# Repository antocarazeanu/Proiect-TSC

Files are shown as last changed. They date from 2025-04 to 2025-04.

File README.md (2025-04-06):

## README - Proiect TSC 2025
## Titlu Proiect: Ebook Reader
## Nume: Carazeanu Antonio-Christian
## Grupa: 332CC

Cuprins:

0. Descrierea generala
1. Diagrama bloc
2. BOM - Bill of Materials
3. Arhitectura hardware
4. Pini utilizați pe ESP32-C6 și justificare
5. Probleme intampinate
6. Observatii

## 0. Descriere Generală:
Proiectul a avut ca scop realizarea unui Ebook Reader ieftin si OpenSource din
perspectiva unui Arhitect de Sistem. Acest dispozitiv poate fi scos pentru a fi
produs in masa.

Am urmat toți pașii standard de proiectare, începând de la schematic, continuând
cu layout-ul PCB, modelare 3D și integrarea finală într-o carcasă.

## 1. Diagrama bloc
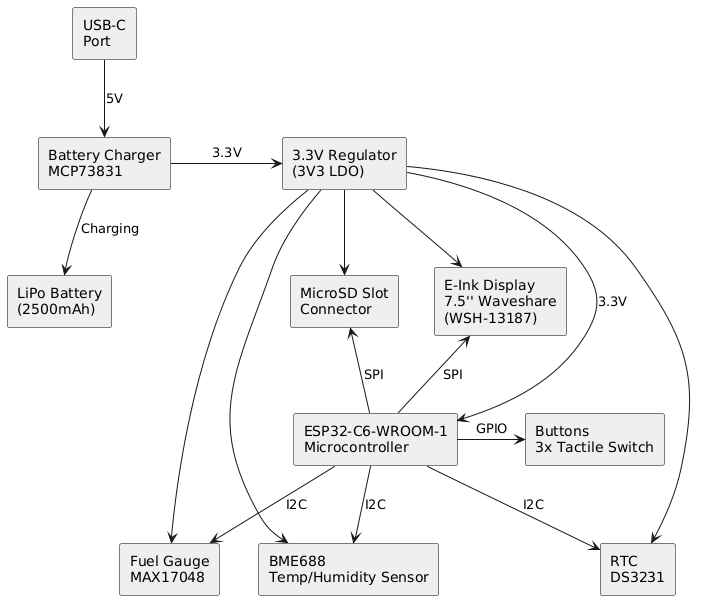
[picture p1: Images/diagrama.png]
Diagrama


## 2. BOM - Bill of Materials
| Device | Value | Check_Price | Datasheet |
|---|---|---|---|
| ADAFRUIT_LEDCHIP-LED0603 | - | [Link](https://www.snapeda.com/parts/KP-1608SURCK/Kingbright/view-part/?ref=search&t=LED%200603) | [Link](https://www.snapeda.com/parts/KP-1608SURCK/Kingbright/datasheet/) |
| SJ | - | [Link](https://grabcad.com/library/solder-jumpers-1) | - |
| EAGLE-LTSPICE_C | 0.1uF/50V | [Link](https://componentsearchengine.com/part-view/CC0402MRX5R5BB106/YAGEO) | [Link](https://componentsearchengine.com/Datasheets/2/CC0402MRX5R5BB106.pdf) |
| ESP32_WROVER_EAGLE-LTSPICE_R | 0.47 | [Link](https://componentsearchengine.com/part-view/R0402%201%25%20100%20K%20(RC0402FR-07100KL)/YAGEO) | [Link](https://www.yageo.com/upload/media/product/products/datasheet/rchip/PYu-RC_Group_51_RoHS_L_12.pdf) |
| ESP32_WROVER_EAGLE-LTSPICE_R | 100K | [Link](https://componentsearchengine.com/part-view/R0402%201%25%20100%20K%20(RC0402FR-07100KL)/YAGEO) | [Link](https://www.yageo.com/upload/media/product/products/datasheet/rchip/PYu-RC_Group_51_RoHS_L_12.pdf) |
| EAGLE-LTSPICE_C | 100nF | [Link](https://componentsearchengine.com/part-view/CC0402MRX5R5BB106/YAGEO) | [Link](https://componentsearchengine.com/Datasheets/2/CC0402MRX5R5BB106.pdf) |
| RCL_CPOL-EUCT3528 | 100uF TANT | [Link](https://www.snapeda.com/parts/TAJB475K025RNJ/AVX/view-part/?ref=dk&t=capacitor%203528&con_ref=None) | [Link](https://s3.amazonaws.com/snapeda/datasheet/TAJB475K025RNJ_AVX.pdf) |
| ESP32_WROVER_EAGLE-LTSPICE_R | 10K | [Link](https://componentsearchengine.com/part-view/R0402%201%25%20100%20K%20(RC0402FR-07100KL)/YAGEO) | [Link](https://www.yageo.com/upload/media/product/products/datasheet/rchip/PYu-RC_Group_51_RoHS_L_12.pdf) |
| EAGLE-LTSPICE_C | 10uF | [Link](https://componentsearchengine.com/part-view/CC0402MRX5R5BB106/YAGEO) | [Link](https://componentsearchengine.com/Datasheets/2/CC0402MRX5R5BB106.pdf) |
| 112A-TAAR-R03_ATTEND | 112A-TAAR-R03_ATTEND | [Link](https://store.comet.srl.ro/Catalogue/Product/43497/) | [Link](https://store.comet.bg/download-file.php?id=8824) |
| ESP32_WROVER_EAGLE-LTSPICE_R | 15 | [Link](https://componentsearchengine.com/part-view/R0402%201%25%20100%20K%20(RC0402FR-07100KL)/YAGEO) | [Link](https://www.yageo.com/upload/media/product/products/datasheet/rchip/PYu-RC_Group_51_RoHS_L_12.pdf) |
| EAGLE-LTSPICE_C | 1uF | [Link](https://componentsearchengine.com/part-view/CC0402MRX5R5BB106/YAGEO) | [Link](https://componentsearchengine.com/Datasheets/2/CC0402MRX5R5BB106.pdf) |
| EAGLE-LTSPICE_C | 1uF/50V | [Link](https://componentsearchengine.com/part-view/CC0402MRX5R5BB106/YAGEO) | [Link](https://componentsearchengine.com/Datasheets/2/CC0402MRX5R5BB106.pdf) |
| ESP32_WROVER_EAGLE-LTSPICE_R | 2.2 | [Link](https://componentsearchengine.com/part-view/R0402%201%25%20100%20K%20(RC0402FR-07100KL)/YAGEO) | [Link](https://www.yageo.com/upload/media/product/products/datasheet/rchip/PYu-RC_Group_51_RoHS_L_12.pdf) |
| ESP32_WROVER_EAGLE-LTSPICE_R | 200 | [Link](https://componentsearchengine.com/part-view/R0402%201%25%20100%20K%20(RC0402FR-07100KL)/YAGEO) | [Link](https://www.yageo.com/upload/media/product/products/datasheet/rchip/PYu-RC_Group_51_RoHS_L_12.pdf) |
| ESP32_WROVER_SPARKFUN-DISCRETESEMI_MOSFET_PCH-DMG2305UX-7 | 20V/4.2A/52m?/1.4W | [Link](https://componentsearchengine.com/part-view/DMG2305UX-7/Diodes%20Incorporated) | [Link](https://www.diodes.com//assets/Datasheets/DMG2305UX.pdf) |
| ESP32_WROVER_EAGLE-LTSPICE_R | 2K | [Link](https://componentsearchengine.com/part-view/R0402%201%25%20100%20K%20(RC0402FR-07100KL)/YAGEO) | [Link](https://www.yageo.com/upload/media/product/products/datasheet/rchip/PYu-RC_Group_51_RoHS_L_12.pdf) |
| EAGLE-LTSPICE_C | 4.7uF | [Link](https://componentsearchengine.com/part-view/CC0402MRX5R5BB106/YAGEO) | [Link](https://componentsearchengine.com/Datasheets/2/CC0402MRX5R5BB106.pdf) |
| EAGLE-LTSPICE_C | 4.7uF/25V | [Link](https://componentsearchengine.com/part-view/CC0402MRX5R5BB106/YAGEO) | [Link](https://componentsearchengine.com/Datasheets/2/CC0402MRX5R5BB106.pdf) |
| ESP32_WROVER_EAGLE-LTSPICE_R | 5k1 | [Link](https://componentsearchengine.com/part-view/R0402%201%25%20100%20K%20(RC0402FR-07100KL)/YAGEO) | [Link](https://www.yageo.com/upload/media/product/products/datasheet/rchip/PYu-RC_Group_51_RoHS_L_12.pdf) |
| 744043680IND_4828-WE-TPC_WRE | 68uH | [Link](https://ro.mouser.com/ProductDetail/Wurth-Elektronik/744043680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.) | [Link](https://www.we-online.com/components/products/datasheet/744043680.pdf) |
| BD5229G-TR | BD5229G-TR | [Link](https://componentsearchengine.com/part-view/BD5229G-TR/ROHM%20Semiconductor) | [Link](https://datasheet.datasheetarchive.com/originals/distributors/Datasheets_SAMA/f2b9741ef86007909f138d561a359946.pdf) |
| ESP32_WROVER_BME680_BME680 | BME688 | [Link](https://www.snapeda.com/parts/BME680/Bosch/view-part/?welcome=home) | [Link](https://www.snapeda.com/parts/BME680/Bosch%20Sensortec/datasheet/) |
| BUTTON_CUSYOMV1V2 | BUTTON_CUSYOMV1V2 | [Link](https://industry.panasonic.com/global/en/products/control/switch/light-touch/number/evqpuj02k) | [Link](https://industry.panasonic.com/global/en/downloads?tab=catalog&small_g_cd=203&part_no=EVQPUJ02K) |
| CPH3225A | CPH3225A | [Link](https://www.snapeda.com/parts/CPH3225A/Seiko+Instruments/view-part/?ref=eda) | [Link](https://www.snapeda.com/parts/CPH3225A/Seiko+Instruments/view-part/?ref=eda ) |
| DS3231SN# | DS3231SN# | [Link](https://www.snapeda.com/parts/DS3231SN%23/Analog+Devices/view-part/?ref=eda) | [Link](https://www.snapeda.com/parts/DS3231SN%23/Analog+Devices/view-part/?ref=eda) |
| ESP32-C6-WROOM-1-N8 | ESP32-C6-WROOM-1-N8 | [Link](https://www.snapeda.com/parts/ESP32-C6-WROOM-1-N8/Espressif+Systems/view-part/?ref=eda) | [Link](https://www.snapeda.com/parts/ESP32-C6-WROOM-1-N8/Espressif+Systems/view-part/?ref=eda) |
| ESP32C6_VARISTORCN1812 | ESP32C6_VARISTORCN1812 | [Link](https://www.mouser.co.uk/ProductDetail/EPCOS-TDK/B72520T0350K062?qs=dEfas%2FXlABIszF52uu7vrg%3D%3D) | [Link](https://www.tdk-electronics.tdk.com/inf/75/db/CTVS_14/Surge_protection_series.pdf) |
| ESP32_WROVER_SPARKFUN-IC-POWER_MCP73831 | ESP32_WROVER_SPARKFUN-IC-POWER_MCP73831 | [Link](https://ro.mouser.com/ProductDetail/Microchip-Technology/MCP73831T-2ACI-OT?qs=yUQqVecv4qvbBQBGbHx0Mw%3D%3D) | [Link](https://ro.mouser.com/datasheet/2/268/MCP73831_Family_Data_Sheet_DS20001984H-3441711.pdf) |
| FH34SRJ-24S-0.5SH_99_ | FH34SRJ-24S-0.5SH_99_ | [Link](https://componentsearchengine.com/part-view/FH34SRJ-24S-0.5SH(99)/Hirose) | [Link](https://www.hirose.com/en/product/document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) |
| MAX17048G+T10 | MAX17048G+T10 | [Link](https://www.snapeda.com/parts/MAX17048G+T10/Analog+Devices/view-part/?ref=eda) | [Link](https://www.snapeda.com/parts/MAX17048G+T10/Analog+Devices/view-part/?ref=eda) |
| MBR0530. | MBR0530. | [Link](https://www.snapeda.com/parts/MBR0530/Onsemi/view-part/?ref=eda) | [Link](https://www.snapeda.com/parts/MBR0530/ON%20Semiconductor/datasheet/) |
| PGB1010603MR. | PGB1010603MR. | [Link](https://www.snapeda.com/parts/PGB1010603MR/Littelfuse/view-part/?ref=eda) | [Link](https://www.snapeda.com/parts/PGB1010603MR/Littelfuse%20Inc./datasheet/) |
| QWIIC_CONNECTORJS-1MM | QWIIC_RIGHT_ANGLE | [Link](https://www.digikey.lt/en/models/926710 ) | [Link](https://www.digikey.lt/en/models/926710) |
| SAMACSYS_PARTS_USB4110-GF-A | SAMACSYS_PARTS_USB4110-GF-A | [Link](https://componentsearchengine.com/part-view/USB4110-GF-A/GCT%20(GLOBAL%20CONNECTOR%20TECHNOLOGY)) | [Link](https://gct.co/files/drawings/usb4110.pdf) |
| ESP32_WROVER_AVX---SD0805S020S1R0_AVX_SD0805S020S1R0_0_0AVX_SD0805S020S1R0_0_0 | SD0805S020S1R0 | [Link](https://ro.mouser.com/ProductDetail/KYOCERA-AVX/SD0805S020S1R0?qs=jCA%252BPfw4LHbpkAoSnwrdjw%3D%3D) | [Link](http://datasheets.avx.com/schottky.pdf) |
| SI1308EDL-T1-GE3 | SI1308EDL-T1-GE3 | [Link](https://www.snapeda.com/parts/SI1308EDL-T1-GE3/Vishay+Siliconix/view-part/?ref=eda) | [Link](https://www.snapeda.com/parts/SI1308EDL-T1-GE3/Vishay+Siliconix/view-part/?ref=eda) |
| TPV1 | TPV1 | Custom made | - |
| USBLC6-2SC6Y | USBLC6-2SC6Y | [Link](https://www.snapeda.com/parts/USBLC6-2SC6Y/STMicroelectronics/view-part/?ref=eda) | [Link](https://www.snapeda.com/parts/USBLC6-2SC6Y/STMicroelectronics/view-part/?ref=eda) |
| W25Q512JVEIQ | W25Q512JVEIQ | [Link](https://www.snapeda.com/parts/W25Q512JVEIQ/Winbond+Electronics/view-part/?ref=eda) | [Link](https://www.snapeda.com/parts/W25Q512JVEIQ/Winbond+Electronics/view-part/?ref=eda) |
| XC6220A331MR-G | XC6220A331MR-G | [Link](https://componentsearchengine.com/part-view/XC6220A331MR-G/Torex) | [Link](https://product.torexsemi.com/system/files/series/xc6220.pdf) |

## 3. Arhitectura Hardware

Descriem în continuare componentele hardware cheie și funcționalitatea acestora în cadrul dispozitivului:

| Nr. | Componentă Principală |
|-----|---|
| 1 | Microcontroller – ESP32-C6-WROOM-1 |
| 2 | Ecran E-Ink – Waveshare WSH-13187, 7.5”  |
| 3 | Senzor Ambiental – Bosch BME688 |
| 4 | Sistem de Alimentare și Baterie |
| 5 | Butoane de Control – 3x Tactile Switch |
| 6 | Conector USB-C |
| 7 | Port Extensie Qwiic / STEMMA QT (I²C) |
| 8 | Soclu MicroSD – Attend 112A-TAAR-R03 |
| 9 | Ceas Timp Real (RTC) – DS3231 |

### 3.1. Unitatea Centrală – Microcontroller ESP32-C6-WROOM-1

-   **Unitate de Procesare:** RISC-V pe 32 de biți, tactat la 160MHz
-   **Memorie:** 512KB SRAM integrat + 8MB memorie flash externă (model W25Q512JVEIQ)
-   **Opțiuni de Comunicare:** Wi-Fi 6 (standard 802.11ax), Bluetooth 5 LE, interfață USB 2.0 Full-Speed
-   **Interfețe Disponibile:** SPI, I²C, UART, multiple porturi GPIO
-   **Consum Energetic:** Sub 50µA în modul deep sleep; diverse moduri de consum redus sunt implementate
-   **Funcții de Securitate:** Include secure boot, criptare pentru memoria flash și accelerare hardware pentru criptografie

### 3.2. Afișajul Electronic – Ecran E-Ink Waveshare WSH-13187, 7.5”

-   **Rezoluție:** 800x480 pixeli, imagine monocromă
-   **Modalitate de Conectare:** Interfață SPI (4 fire) plus linii de control CS, DC, RST, BUSY
-   **Consum Energetic:** Aproximativ 15–25mA în timpul actualizării imaginii; consum neglijabil în stare statică
-   **Rațiunea Alegerii:** Consumul energetic aproape nul când imaginea nu se schimbă, optim pentru aplicații tip e-reader

### 3.3. Senzorul Ambiental Integrat – Bosch BME688

-   **Parametri Măsurați:** Temperatură, Umiditate relativă, Presiune atmosferică, Indice al Calității Aerului (estimare eCO2, TVOC)
-   **Acuratețe:** ±1°C pentru temperatură, ±3% pentru umiditate, ±1 hPa pentru presiune
-   **Modalitate de Conectare:** Interfață I²C (operând la 400kHz)
-   **Consum Energetic:** 2.1µA în standby, maxim 3.6mA în timpul măsurătorilor active
-   **Rațiunea Alegerii:** Soluție compactă multi-senzor, potrivită pentru monitorizarea condițiilor ambientale

### 3.4. Sistemul de Alimentare și Gestionarea Energiei

-   **Sursa de Energie:** Acumulator Li-Po de 3.7V cu o capacitate de 2500mAh
-   **Monitorizare Baterie:** Circuit integrat MAX17048 (comunică prin I²C)
-   **Circuit de Încărcare:** MCP73831 – permite încărcarea cu 5V/1A via portul USB-C
-   **Regulator de Tensiune:** LDO ce furnizează o tensiune stabilă de 3.3V pentru întregul circuit
-   **Consum Total Estimativ:**
    -   În mod activ: între 100 și 150mA
    -   În mod deep sleep: sub 50µA

### 3.5. Interfața cu Utilizatorul – 3x Butoane Tactile

-   **Model Buton:** Panasonic EVQ-Q2A03W
-   **Conectare Electrică:** Legate la pini GPIO, cu circuit de debounce hardware (filtru RC)
-   **Funcționalități Asignate:** Navigare prin meniuri, avansare/revenire pagină, confirmare acțiuni

### 3.6. Conectorul USB-C

-   **Funcționalități Principale:** Încărcarea bateriei și transferul de date (conform standardului USB 2.0)
-   **Măsuri de Protecție:** Protecție ESD integrată și terminații conforme standardului
-   **Posibilități Suplimentare:** Actualizări software OTA (Over-The-Air) via Wi-Fi sau actualizare firmware prin conexiune USB

### 3.7. Portul de Extensie Qwiic / STEMMA QT (I²C)

-   **Configurație Pini:** VCC (Alimentare), GND (Masă), SDA (Date I²C), SCL (Ceas I²C)
-   **Scop/Beneficii:** Permite conectarea rapidă a modulelor și senzorilor externi compatibili I²C

### 3.8. Soclul pentru Card MicroSD – Attend 112A-TAAR-R03

-   **Rol Principal:** Oferă spațiu de stocare extern (pentru cărți electronice, fișiere jurnal, firmware etc.)
-   **Modalitate de Conectare:** Interfață SPI

### 3.9. Ceasul Timp Real (RTC) – DS3231

-   **Acuratețe:** Deviație maximă de ±2 părți per milion (ppm)
-   **Modalitate de Conectare:** Interfață I²C
-   **Alimentare de Backup:** Asigurată de un supercapacitor

---

### Protocoale de Comunicare și Interfețe Utilizate

| Protocol/Interfață | Componente Conectate |
|---|---|
| **SPI** | Ecran E-Paper, Memorie Flash externă, Card SD (SPI) |
| **I²C** | Senzor BME688, Fuel Gauge MAX17048, RTC DS3231, Port Qwiic/Stemma |
| **USB** | Încărcare și comunicație de date via USB-C |
| **GPIO** | Butoane, Linii control afișaj, Activare încărcare |

---

### Profil de Consum Energetic (Estimări)

| Stare/Componentă | Consum Estimativ |
|---|---|
| ESP32-C6 (mod activ) | 80–100mA |
| Actualizare E-Paper | 15–25mA |
| Senzor BME688 (activ)  | 3.6mA |
| Fuel Gauge MAX17048 | ~50µA |
| RTC DS3231 | 3.5mA / 1µA backup |
| Deep Sleep (Total) | <50–100µA |

---

### Specificații Fizice și Constructive

-   **Mărimi Fizice:** 175 x 114 x 10 mm
-   **Masa Dispozitivului:** Aproximativ 250g
-   **Material Carcasă:** ABS sau policarbonat, cu design ergonomic
-   **Montare Afișaj:** Integrat într-un decupaj specific al carcasei
-   **Detalii de Fabricație:** PCB cu 2 straturi, finisaj ENIG, carcasă obținută prin injecție de plastic

## 4. Pini utilizați pe ESP32-C6 și justificare

| Pin ESP32-C6 | Componentă / Semnal | De ce? |
|---|---|---|
| GPIO1 | I²C SDA (BME688, MAX17048, DS3231, Qwiic) | Linie partajată I²C – economisește pini și permite extinderea facilă |
| GPIO2 | I²C SCL (BME688, MAX17048, DS3231, Qwiic) | Clock I²C pentru toți senzorii și extensii Qwiic |
| GPIO5 | SPI MISO (E-Paper, Flash extern) | Linie comună de intrare date în SPI |
| GPIO6 | SPI MOSI (E-Paper, Flash extern) | Linie de ieșire date către e-paper și flash |
| GPIO7 | SPI CLK | Semnal de clock pentru magistrala SPI |
| GPIO8 | E-Paper CS | Selectează afișajul pe magistrala SPI |
| GPIO9 | E-Paper DC (Data/Command) | Comută între comandă și date către e-paper |
| GPIO10 | E-Paper RST | Reset hardware e-paper |
| GPIO11 | E-Paper BUSY | Pin de stare (ocupat/liber) de la display |
| GPIO12 | Button #1 | Intrare digitală pentru navigare pagină înainte |
| GPIO13 | Button #2 | Intrare digitală pentru navigare pagină înapoi |
| GPIO14 | Button #3 | Intrare digitală pentru selectare/opțiune |
| GPIO15 | MAX17048 ALERT (opțional) | Pin de alertă nivel scăzut baterie |
| GPIO16 | USB D+ (intern la USB PHY) | Linie USB 2.0 (fixă pe ESP32-C6) |
| GPIO17 | USB D- (intern la USB PHY) | Linie USB 2.0 (fixă pe ESP32-C6) |
| GPIO18 | LED Status (opțional) | Indicator pentru activitate Wi-Fi, charging, notificări |
| GPIO19 | SD Card CS | Selectare chip pentru card microSD (SPI) |
| GPIO20 | SD Card MISO | Citire date de pe card microSD |
| GPIO21 | SD Card MOSI | Scriere date pe card microSD |
| GPIO4 | SD Card CLK | Semnal de clock pentru card microSD (SPI) |

## 5. Probleme intampinate
1) La partea de 3D am întâmpinat o problemă semnificativă — modelele 3D ale rezistențelor și condensatoarelor nu se actualizau automat în PCB atunci când încercam să folosesc funcția Replace Package. Pentru a rezolva această problemă, a trebuit să adaug manual modelele 3D custom realizate pentru fiecare componentă în parte.

2) Bobina si mufa USB au avut dimensiunea pad-urilor mai mica decat grosimea firelor, marint astfel pad-urile din footprint pentru a putea face lipirea.

## 6. Observatii
Un proiect mult prea muncitoresc care nu merita doar 2pct din nota.
Timp de lucru aprox ~70h

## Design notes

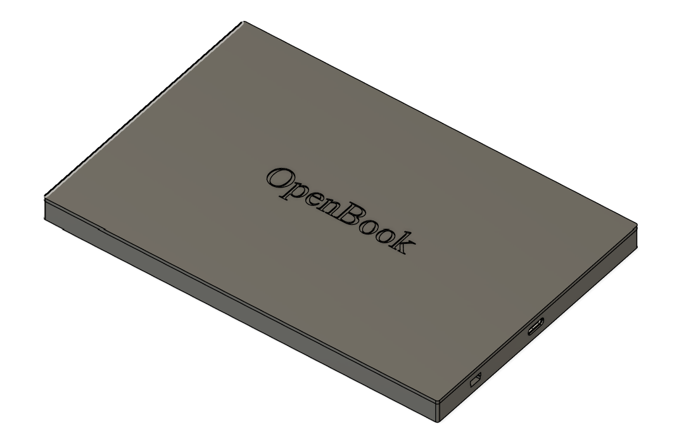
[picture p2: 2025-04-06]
Images/spate_tableta.png

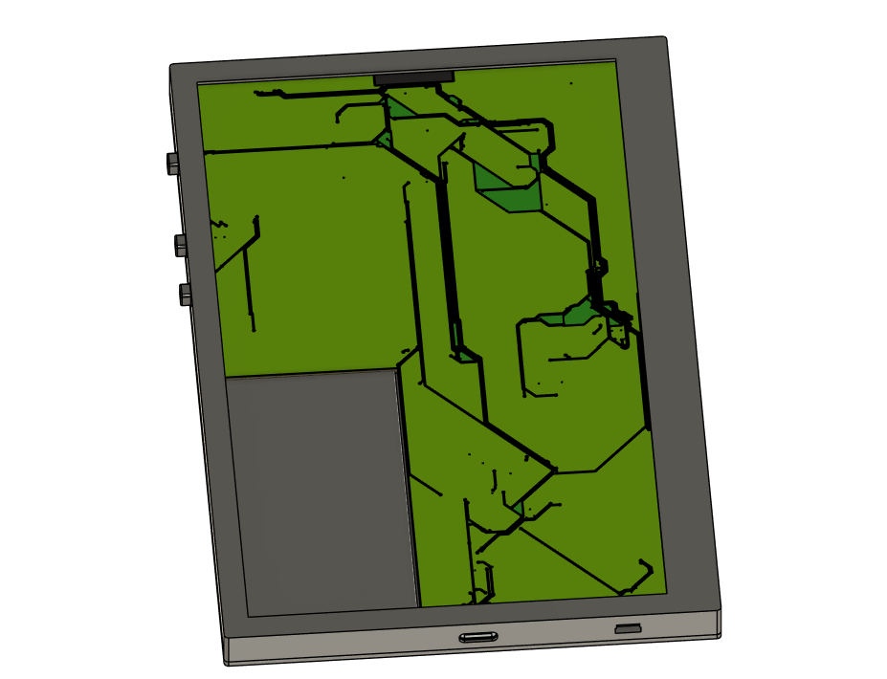
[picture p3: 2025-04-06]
Images/tableta_fara_ecran.png

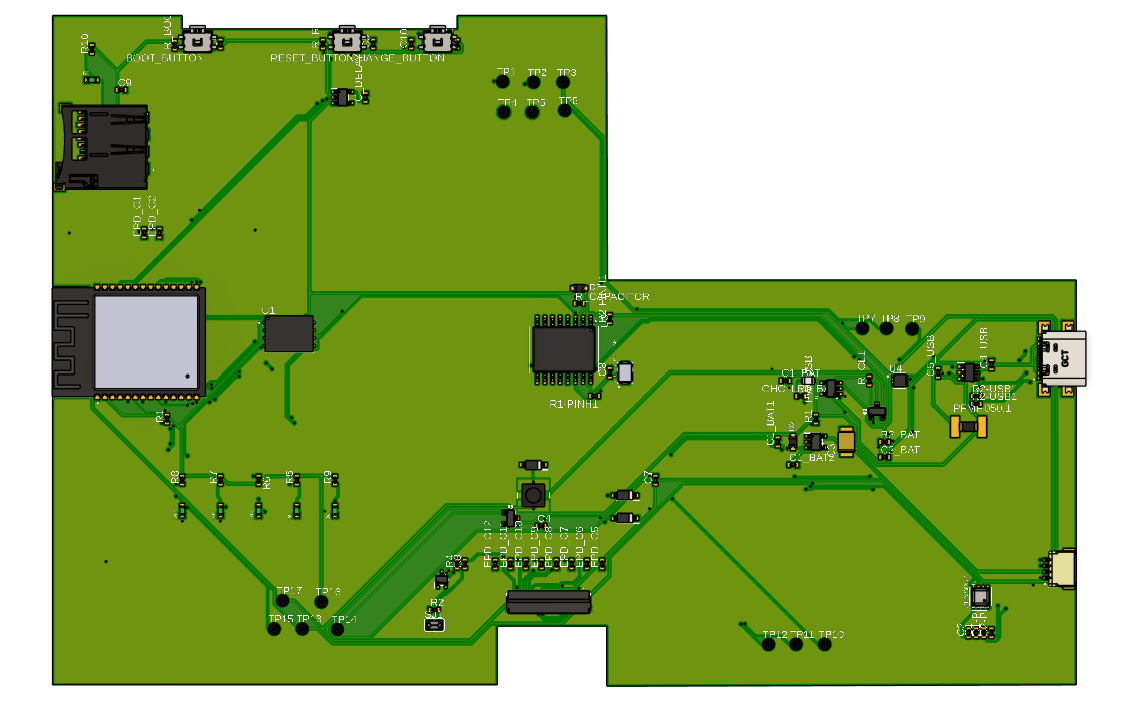
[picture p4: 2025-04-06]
Images/pcb_3d_top.png

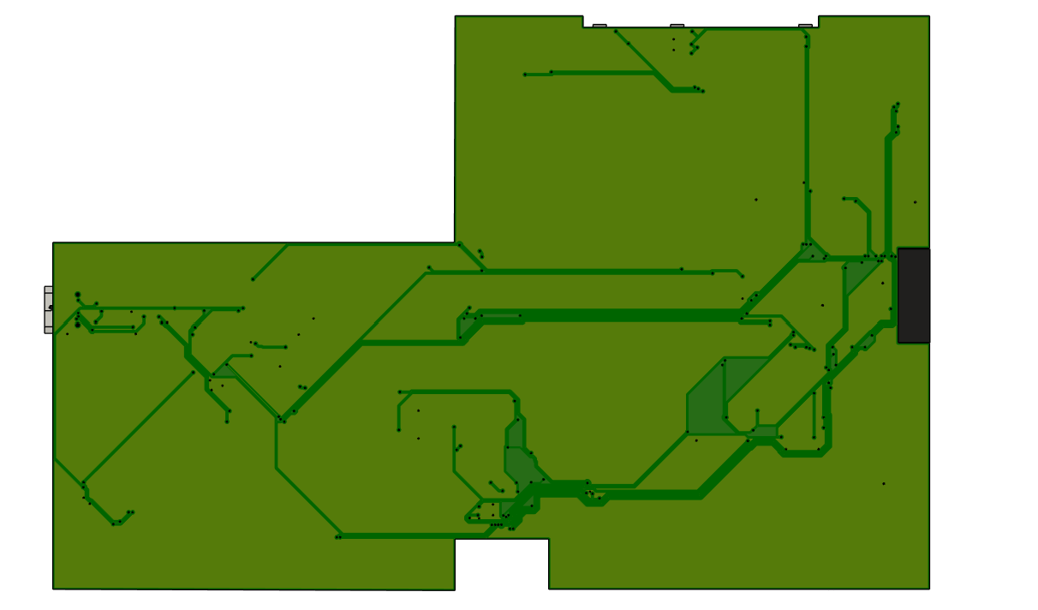
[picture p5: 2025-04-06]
Images/pcb_3d_bottom.png

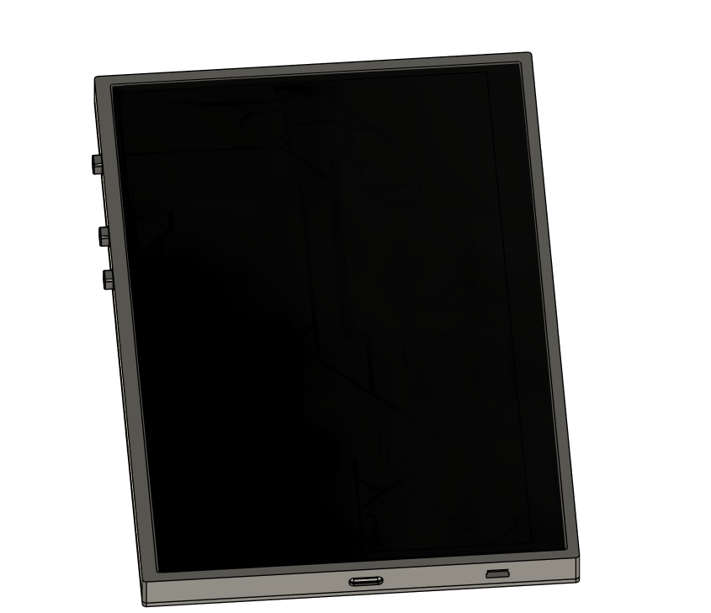
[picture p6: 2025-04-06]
Images/tableta.png

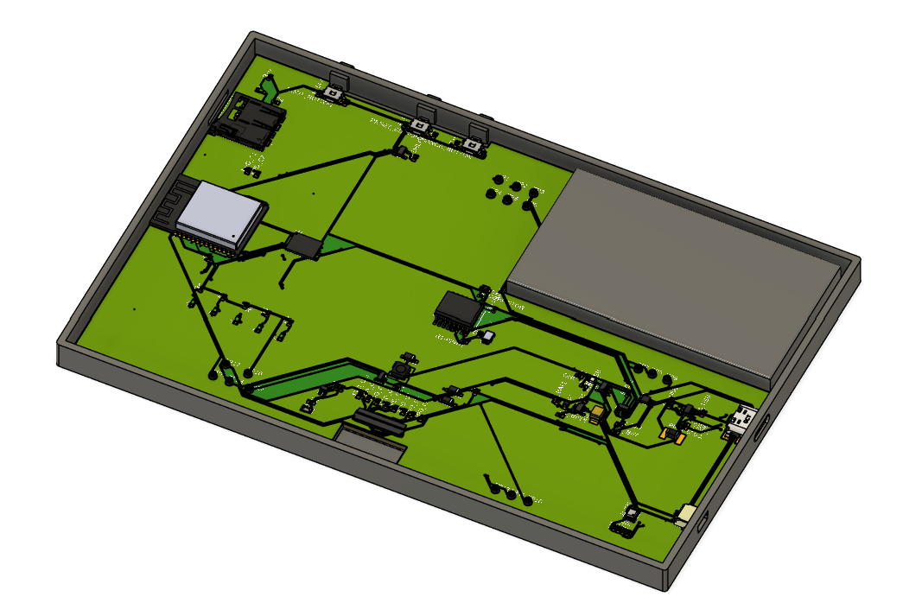
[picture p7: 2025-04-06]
Images/baterie.png

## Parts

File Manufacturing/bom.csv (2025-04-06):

Qty | Value | Device | Package | Parts | Description | ARROW_PART_NUMBER | ARROW_PRICE-STOCK | AVAILABILITY | CENTROID_NOT_SPECIFIED | CHECK_PRICES | COPYRIGHT | DATASHEET | DESCRIPTION | DIGIKEY_DESCRIPTION | DIGIKEY_PART_NUMBER | HEIGHT | LEAD_FREE | MANUFACTURER_NAME | MANUFACTURER_PART_NUMBER | MF | MFR_NAME | MOUSER_PART_NUMBER | MOUSER_PRICE-STOCK | MOUSER_TESTING_PART_NUMBER | MOUSER_TESTING_PRICE-STOCK | MP | MPN | PACKAGE | POPULARITY | PREFIX | PRICE | PROD_ID | PURCHASE-URL | ROHS | SNAPEDA_LINK | SPICEMODEL | SPICEPREFIX | TEMPERATURE_RANGE_HIGH | TEMPERATURE_RANGE_LOW | TP_SIGNAL_NAME | VALUE
1 |  | ADAFRUIT_LEDCHIP-LED0603 | ADAFRUIT_CHIP-LED0603 | GHC_LED | LED
1 |  | ESP32_WROVER_EAGLE-LTSPICE_RR0402 | ESP32_WROVER_EAGLE-LTSPICE_R0402 | R_CAPACITOR | RESISTOR, European symbol |  |  |  |  |  |  |  |  |  |  |  |  |  |  |  |  |  |  |  |  |  |  |  |  |  |  |  |  |  |  | NONE | R
1 |  | SJ | SJ | SJ1 | SMD solder JUMPER |  |  |  |  |  |  |  |  |  |  |  |  |  |  |  |  |  |  |  |  |  |  |  | 3
1 | 0.1uF/50V | ESP32_WROVER_EAGLE-LTSPICE_CC0402 | ESP32_WROVER_EAGLE-LTSPICE_C0402 | EPD_C5 | CAPACITOR, European symbol |  |  |  |  |  |  |  |  |  |  |  |  |  |  |  |  |  |  |  |  |  |  |  |  |  |  |  |  |  |  | NONE | C
1 | 0.47 | ESP32_WROVER_EAGLE-LTSPICE_RR0402 | ESP32_WROVER_EAGLE-LTSPICE_R0402 | R3 | RESISTOR, European symbol |  |  |  |  |  |  |  |  |  |  |  |  |  |  |  |  |  |  |  |  |  |  |  |  |  |  |  |  |  |  | NONE | R
1 | 100k | ESP32_WROVER_EAGLE-LTSPICE_RR0402 | ESP32_WROVER_EAGLE-LTSPICE_R0402 | R1_PWRUSB | RESISTOR, European symbol |  |  |  |  |  |  |  |  |  |  |  |  |  |  |  |  |  |  |  |  |  |  |  |  |  |  |  |  |  |  | NONE | R
8 | 100nF | ESP32_WROVER_EAGLE-LTSPICE_CC0402 | ESP32_WROVER_EAGLE-LTSPICE_C0402 | C1, C2, C4_USB, C6, C8, C9, C10, C_DELAY | CAPACITOR, European symbol |  |  |  |  |  |  |  |  |  |  |  |  |  |  |  |  |  |  |  |  |  |  |  |  |  |  |  |  |  |  | NONE | C
1 | 100uF TANT | RCL_CPOL-EUCT3528 | RCL_CT3528 | C3 | POLARIZED CAPACITOR, European symbol |  |  |  |  |  |  |  |  |  |  |  |  |  |  |  |  |  |  |  |  |  |  |  | 0 |  |  |  |  |  |  |  | C
16 | 10k | ESP32_WROVER_EAGLE-LTSPICE_RR0402 | ESP32_WROVER_EAGLE-LTSPICE_R0402 | R1, R1-PINH, R1-PINH1, R2-PINH, R2-PINH1, R4, R5, R6, R7, R8, R9, R10, R_BOOT, R_CHANGE, R_CL1, R_RESET | RESISTOR, European symbol |  |  |  |  |  |  |  |  |  |  |  |  |  |  |  |  |  |  |  |  |  |  |  |  |  |  |  |  |  |  | NONE | R
1 | 10uF | ESP32_WROVER_EAGLE-LTSPICE_CC0402 | ESP32_WROVER_EAGLE-LTSPICE_C0402 | C7 | CAPACITOR, European symbol |  |  |  |  |  |  |  |  |  |  |  |  |  |  |  |  |  |  |  |  |  |  |  |  |  |  |  |  |  |  | NONE | C
1 | 112A-TAAR-R03_ATTEND | 112A-TAAR-R03_ATTEND | 112ATAARR03ATTEND | J4 | Micro SD Card Socket, Push-Push Type, Top Mount, SMT, H=1.83mm, 10u |  |  |  |  |  |  |  | Micro SD Card Socket | Push-Push Type | Top Mount | SMT | H=1.83mm | 10u |  |  | 1.9mm |  | ATTEND | 112A-TAAR-R03 ATTEND
1 | 1uF | ESP32_WROVER_EAGLE-LTSPICE_CC0402 | ESP32_WROVER_EAGLE-LTSPICE_C0402 | C5 | CAPACITOR, European symbol |  |  |  |  |  |  |  |  |  |  |  |  |  |  |  |  |  |  |  |  |  |  |  |  |  |  |  |  |  |  | NONE | C
9 | 1uF/50V | ESP32_WROVER_EAGLE-LTSPICE_CC0402 | ESP32_WROVER_EAGLE-LTSPICE_C0402 | EPD_C1, EPD_C2, EPD_C6, EPD_C7, EPD_C8, EPD_C9, EPD_C10, EPD_C11, EPD_C12 | CAPACITOR, European symbol |  |  |  |  |  |  |  |  |  |  |  |  |  |  |  |  |  |  |  |  |  |  |  |  |  |  |  |  |  |  | NONE | C
1 | 2.2 | ESP32_WROVER_EAGLE-LTSPICE_RR0402 | ESP32_WROVER_EAGLE-LTSPICE_R0402 | R2 | RESISTOR, European symbol |  |  |  |  |  |  |  |  |  |  |  |  |  |  |  |  |  |  |  |  |  |  |  |  |  |  |  |  |  |  | NONE | R
1 | 200 | ESP32_WROVER_EAGLE-LTSPICE_RR0402 | ESP32_WROVER_EAGLE-LTSPICE_R0402 | R1_BAT | RESISTOR, European symbol |  |  |  |  |  |  |  |  |  |  |  |  |  |  |  |  |  |  |  |  |  |  |  |  |  |  |  |  |  |  | NONE | R
2 | 20V/4.2A/52mO/1.4W | ESP32_WROVER_SPARKFUN-DISCRETESEMI_MOSFET_PCH-DMG2305UX-7 | ESP32_WROVER_SPARKFUN-DISCRETESEMI_SOT23-3 | Q2, Q3 | P-channel MOSFETs |  |  |  |  |  |  |  |  |  |  |  |  |  |  |  |  |  |  |  |  |  |  |  |  |  |  | TRAN-14388 |  |  |  |  |  |  |  |  | 20V/4.2A/52mO/1.4W
1 | 2k | ESP32_WROVER_EAGLE-LTSPICE_RR0402 | ESP32_WROVER_EAGLE-LTSPICE_R0402 | R2_BAT | RESISTOR, European symbol |  |  |  |  |  |  |  |  |  |  |  |  |  |  |  |  |  |  |  |  |  |  |  |  |  |  |  |  |  |  | NONE | R
3 | 4.7uF | EAGLE-LTSPICE_CC0402 | EAGLE-LTSPICE_C0402 | C1_BAT, C1_BAT1, C2_BAT | CAPACITOR, European symbol |  |  |  |  |  |  |  |  |  |  |  |  |  |  |  |  |  |  |  |  |  |  |  |  |  |  |  |  |  |  | NONE | C
1 | 4.7uF | ESP32_WROVER_EAGLE-LTSPICE_CC0402 | ESP32_WROVER_EAGLE-LTSPICE_C0402 | C5_USB | CAPACITOR, European symbol |  |  |  |  |  |  |  |  |  |  |  |  |  |  |  |  |  |  |  |  |  |  |  |  |  |  |  |  |  |  | NONE | C
1 | 4.7uF/25V | ESP32_WROVER_EAGLE-LTSPICE_CC0402 | ESP32_WROVER_EAGLE-LTSPICE_C0402 | C4 | CAPACITOR, European symbol |  |  |  |  |  |  |  |  |  |  |  |  |  |  |  |  |  |  |  |  |  |  |  |  |  |  |  |  |  |  | NONE | C
1 | 4.7uf | EAGLE-LTSPICE_CC0402 | EAGLE-LTSPICE_C0402 | C1_BAT2 | CAPACITOR, European symbol |  |  |  |  |  |  |  |  |  |  |  |  |  |  |  |  |  |  |  |  |  |  |  |  |  |  |  |  |  |  | NONE | C
2 | 5k1 | ESP32_WROVER_EAGLE-LTSPICE_RR0402 | ESP32_WROVER_EAGLE-LTSPICE_R0402 | R2-USB, R2-USB1 | RESISTOR, European symbol |  |  |  |  |  |  |  |  |  |  |  |  |  |  |  |  |  |  |  |  |  |  |  |  |  |  |  |  |  |  | NONE | R
1 | 68uH | 744043680IND_4828-WE-TPC_WRE | IND_4828-WE-TPC_WRE | L1 |  |  |  |  |  |  | Copyright (C) 2024 Ultra Librarian. All rights reserved. |  |  |  |  |  |  |  | 744043680 |  | Wurth Electronics
1 | BD5229G-TR | BD5229G-TR | SOT95P280X125-5N | IC1 | Voltage Detector with Adjustable Delay Time: CMOS processes are utilized to develop high precision, low current consumption CMOS reset ICs that allow arbitrary setting of the delay time. The extensive lineup includes both Nch Open Drain and CMOS output types in a wide range of detection voltages (from 2.3V to 6.0V, in 0.1V steps), enabling selection of the ideal solution based on customer requirements. In addition, the entire series is of course both lead-free and RoHS-compliant. |  |  |  |  |  |  |  | Voltage Detector with Adjustable Delay Time: CMOS processes are utilized to develop high precision | low current consumption CMOS reset ICs that allow arbitrary setting of the delay time. The extensive lineup includes both Nch Open Drain and CMOS output types in a wide range of detection voltages (from 2.3V to 6.0V | in 0.1V steps) | enabling selection of the ideal solution based on customer requirements. In addition | the entire series is of course both lead-free and RoHS-compliant. |  |  | 1.25mm |  | ROHM Semiconductor | BD5229G-TR |  |  | 755-BD5229G-TR | https://www.mouser.co.uk/ProductDetail/ROHM-Semiconductor/BD5229G-TR?qs=4kLU8WoGk0vvnhrrYwdszw%3D%3D
3 | BUTTON_CUSYOMV1 | BUTTON_CUSYOMV1 | MYBUTTON | BOOT_BUTTON, CHANGE_BUTTON, RESET_BUTTON
1 | CPH3225A | CPH3225A | CAPCP3225X100N | C10_SUPERCAP | Cap 0.011F 3.3V 1210 Flat Check availability |  |  | Not in stock |  | https://www.snapeda.com/parts/CPH3225A/Seiko+Instruments/view-part/?ref=eda |  |  | 11 mF (EDLC) Supercapacitor 3.3 V 1210 (3225 Metric) - - |  |  |  |  |  |  | Seiko Instruments |  |  |  |  |  | CPH3225A |  | 1210 Seiko |  |  | None |  | https://www.snapeda.com/api/url_track_click_mouser/?unipart_id=562593&manufacturer=Seiko Instruments&part_name=CPH3225A&search_term=None |  | https://www.snapeda.com/parts/CPH3225A/Seiko+Instruments/view-part/?ref=snap
1 | DS3231SN# | DS3231SN# | SOIC127P1032X265-16N | U3 | Real Time Clock Serial 16-Pin SOIC W T/R Check availability |  |  | In Stock |  | https://www.snapeda.com/parts/DS3231SN%23/Analog+Devices/view-part/?ref=eda |  |  | Extremely Accurate I²C-Integrated RTC/TCXO/Crystal |  |  |  |  |  |  | Analog Devices |  |  |  |  |  | DS3231SN# |  | SOIC-16 Maxim |  |  | None |  | https://www.snapeda.com/api/url_track_click_mouser/?unipart_id=99048&manufacturer=Analog Devices&part_name=DS3231SN#&search_term=None |  | https://www.snapeda.com/parts/DS3231SN%23/Analog+Devices/view-part/?ref=snap
1 | ESP32-C6-WROOM-1-N8 | ESP32-C6-WROOM-1-N8 | XCVR_ESP32-C6-WROOM-1-N8 | U2 | Check availability |  |  | In Stock |  | https://www.snapeda.com/parts/ESP32-C6-WROOM-1-N8/Espressif+Systems/view-part/?ref=eda |  |  | Multiprotocol Modules ESP32-C6 module | Wi-Fi 6 in 2.4 GHz band | Bluetooth 5 | Zigbee 3.0 and Thread. ESP34-WROOM Compatible - ENGINEERING SAMPLE |  |  |  |  |  |  | Espressif Systems |  |  |  |  |  | ESP32-C6-WROOM-1-N8 |  | None |  |  | None |  |  |  | https://www.snapeda.com/parts/ESP32-C6-WROOM-1-N8/Espressif+Systems/view-part/?ref=snap
1 | ESP32C6_VARISTORCN1812 | ESP32C6_VARISTORCN1812 | ESP32C6_VARISTOR_CT/CN1812 | PFMF.050.1 | VARISTOR |  |  |  |  |  |  |  |  |  |  |  |  |  |  |  |  |  |  |  |  |  |  |  | 0
2 | ESP32_WROVER_AVX---SD0805S020S1R0_AVX_SD0805S020S1R0_0_0AVX_SD0805S020S1R0_0_0 | ESP32_WROVER_AVX---SD0805S020S1R0_AVX_SD0805S020S1R0_0_0AVX_SD0805S020S1R0_0_0 | ESP32_WROVER_AVX---SD0805S020S1R0_AVX_SD0805S020S1R0_0 | D2, D7 | Schottky Barrier Rectifier Diode |  |  |  | No |  |  | http://datasheets.avx.com/schottky.pdf |  | DIODE SCHOTTKY 20V 1A 0805 | 478-7800-1-ND |  | yes |  |  | AVX |  | 581-SD0805S020S1R0 |  |  |  |  |  | 0805 (2012 metric) |  | D |  |  |  | yes |  |  |  | +125°C | -55°C
1 | ESP32_WROVER_BME680_BME680 | ESP32_WROVER_BME680_BME680 | ESP32_WROVER_BME680_PSON80P300X300X100-8N | SENSOR2 | Integrated Environmental Unit |  |  | Unavailable |  |  |  |  | Integrated Environmental Unit |  |  |  |  |  |  | Bosch Sensortec |  |  |  |  |  | BME680 |  | LGA-8 Bosch Tools |  |  | None
1 | ESP32_WROVER_SPARKFUN-IC-POWER_MCP73831 | ESP32_WROVER_SPARKFUN-IC-POWER_MCP73831 | ESP32_WROVER_SPARKFUN-IC-POWER_SOT23-5 | U | MCP73831T Li-Ion, Li-Pol Controller |  |  |  |  |  |  |  |  |  |  |  |  |  |  |  |  |  |  |  |  |  |  |  |  |  |  | IC-09995
1 | FH34SRJ-24S-0.5SH_99_ | FH34SRJ-24S-0.5SH_99_ | FH34SRJ24S05SH99 | J1 | (0.50mm) Surface Mount, Right Angle |  |  |  |  |  |  |  | 24 Position FFC | FPC Connector Contacts | (0.50mm) Surface Mount | Right Angle |  |  | 1.1mm |  | Hirose | FH34SRJ-24S-0.5SH(99) |  |  | 798-FH34SRJ24S05SH99 | https://www.mouser.co.uk/ProductDetail/Hirose-Connector/FH34SRJ-24S-0.5SH99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
1 | MAX17048G+T10 | MAX17048G+T10 | SON50P200X200X80-9N | U4 | Check availability |  |  | In Stock |  | https://www.snapeda.com/parts/MAX17048G+T10/Analog+Devices/view-part/?ref=eda |  |  | 3µA 1-Cell/2-Cell Fuel Gauge with ModelGauge |  |  |  |  |  |  | Analog Devices |  |  |  |  |  | MAX17048G+T10 |  | TDFN-8 Maxim |  |  | None |  | https://www.snapeda.com/api/url_track_click_mouser/?unipart_id=329239&manufacturer=Analog Devices&part_name=MAX17048G+T10&search_term=None |  | https://www.snapeda.com/parts/MAX17048G+T10/Analog+Devices/view-part/?ref=snap
3 | MBR0530 | MBR0530 | SOD3716X135N | D3, D4, D5 | ON SEMICONDUCTOR - MBR0530 - DIODE, SCHOTTKY, 0.5A, 30V, SOD-123 |  |  | In Stock |  | https://www.snapeda.com/parts/MBR0530/Onsemi/view-part/?ref=eda |  |  | Diode Schottky 30 V 500mA Surface Mount SOD-123 |  |  |  |  |  |  | ON Semiconductor |  |  |  |  |  | MBR0530 |  | SOD-123-2 ON Semiconductor |  |  | None |  | https://www.snapeda.com/api/url_track_click_mouser/?unipart_id=179458&manufacturer=ON Semiconductor&part_name=MBR0530&search_term=None |  | https://www.snapeda.com/parts/MBR0530/Onsemi/view-part/?ref=snap
6 | PGB1010603MR | PGB1010603MR | DIOC1608X36N | D6, D8, D9, D10, D11, D12 | Check availability |  |  | In Stock |  | https://www.snapeda.com/parts/PGB1010603MR/Littelfuse/view-part/?ref=eda |  |  | 150V (Typ) Clamp - Ipp Tvs Diode Surface Mount 0603 (1608 Metric) |  |  |  |  |  |  | Littelfuse Inc. |  |  |  |  |  | PGB1010603MR |  | 0603 Littelfuse Inc. |  |  | None |  | https://www.snapeda.com/api/url_track_click_mouser/?unipart_id=5659453&manufacturer=Littelfuse Inc.&part_name=PGB1010603MR&search_term=None |  | https://www.snapeda.com/parts/PGB1010603MR/Littelfuse/view-part/?ref=snap
1 | QWIIC_RIGHT_ANGLE | QWIIC_CONNECTORJS-1MM | JST04_1MM_RA | J3 | SparkFun I2C Standard Qwiic Connector |  |  |  |  |  |  |  |  |  |  |  |  |  |  |  |  |  |  |  |  |  |  |  |  |  |  | CONN-13694 |  |  |  |  |  |  |  |  | QWIIC_RIGHT_ANGLE
1 | SAMACSYS_PARTS_USB4110-GF-A | SAMACSYS_PARTS_USB4110-GF-A | SAMACSYS_PARTS_USB4110GFA | J2 | CONN USB 2.0 TYPE-C R/A SMT |  |  |  |  |  |  |  | CONN USB 2.0 TYPE-C R/A SMT |  |  | 3.26mm |  | GCT (GLOBAL CONNECTOR TECHNOLOGY) | USB4110-GF-A |  |  | 640-USB4110-GF-A | https://www.mouser.co.uk/ProductDetail/GCT/USB4110-GF-A?qs=KUoIvG%2F9IlYiZvIXQjyJeA%3D%3D
1 | SI1308EDL-T1-GE3 | SI1308EDL-T1-GE3 | SOT65P210X110-3N | Q1 | MOSFET N-Ch 30V 1.5A TrenchFET SC70 Vishay Si1308EDL-T1-GE3 N-channel MOSFET Transistor, 1.5 A, 30 V, 3-Pin SC-70 |  |  | In Stock |  | https://www.snapeda.com/parts/SI1308EDL-T1-GE3/Vishay+Siliconix/view-part/?ref=eda |  |  | Si1308EDL-T1-GE3 N-channel MOSFET Transistor | 1.5 A | 30 V | 3-Pin SC-70 | Siliconix / Vishay SI1308EDL-T1-GE3 |  |  |  |  |  |  | Vishay Siliconix |  |  |  |  |  | SI1308EDL-T1-GE3 |  | SOT-323 Vishay Semiconductor |  |  | None |  | https://www.snapeda.com/api/url_track_click_mouser/?unipart_id=274603&manufacturer=Vishay Siliconix&part_name=SI1308EDL-T1-GE3&search_term=None |  | https://www.snapeda.com/parts/SI1308EDL-T1-GE3/Vishay+Siliconix/view-part/?ref=snap
17 | TPTP20R | TPTP20R | TP20R | TP1, TP2, TP3, TP4, TP5, TP6, TP7, TP8, TP9, TP10, TP11, TP12, TP13, TP14, TP15, TP16, TP17 | Test pad |  |  |  |  |  |  |  |  |  |  |  |  |  |  |  |  |  |  |  |  |  |  |  | 2
1 | USBLC6-2SC6Y | USBLC6-2SC6Y | SOT95P280X145-6N | D1 | Low Cap. ESD Protection Auto SOT-23-6 STMicroelectronics USBLC6-2SC6Y, Dual Uni-Directional TVS Diode Array, 6-Pin SOT-23 |  |  | In Stock |  | https://www.snapeda.com/parts/USBLC6-2SC6Y/STMicroelectronics/view-part/?ref=eda |  |  | 17V Clamp 5A (8/20µs) Ipp Tvs Diode Surface Mount SOT-23-6 |  |  |  |  |  |  | STMicroelectronics |  |  |  |  |  | USBLC6-2SC6Y |  | SOT-23-6 STMicroelectronics |  |  | None |  |  |  | https://www.snapeda.com/parts/USBLC6-2SC6Y/STMicroelectronics/view-part/?ref=snap
1 | W25Q512JVEIQ | W25Q512JVEIQ | SON127P600X800X80-9N | U1 | Check availability |  |  | In Stock |  | https://www.snapeda.com/parts/W25Q512JVEIQ/Winbond+Electronics/view-part/?ref=eda |  |  | FLASH - NOR Memory IC 512Mb (64M x 8) SPI - Quad I/O 133 MHz 8-WSON (8x6) |  |  |  |  |  |  | Winbond Electronics |  |  |  |  |  | W25Q512JVEIQ |  | Package |  |  | None |  |  |  | https://www.snapeda.com/parts/W25Q512JVEIQ/Winbond+Electronics/view-part/?ref=snap
1 | XC6220A331MR-G | XC6220A331MR-G | SOT95P280X120-5N | IC4 | LDO Voltage Regulators |  |  |  |  |  |  |  | LDO Voltage Regulators |  |  | 1.2mm |  | Torex | XC6220A331MR-G |  |  | 865-XC6220A331MR-G | https://www.mouser.co.uk/ProductDetail/Torex-Semiconductor/XC6220A331MR-G?qs=AsjdqWjXhJ8ZSWznL1J0gg%3D%3D

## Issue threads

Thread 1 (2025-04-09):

CAD ERC Warnings

madalinaandronache, 2025-04-09:
Acest issue urmărește problemele legate de Schematic identificate în timpul review-ului:
- [x] Close but unconnected wires
- [x] Net PREVGH overlaps pin
- [x] No pins on net N$4

Closed 2025-04-10.

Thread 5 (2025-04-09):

Schematic block titles missing

madalinaandronache, 2025-04-09:
Documentul de referinta conține titluri de secțiuni precum „USB C connector & ESD protection”, „LDO Voltage Regulator” etc., însă acestea nu sunt prezente in schematic, ceea ce il face greu de citit.

Closed 2025-04-10.

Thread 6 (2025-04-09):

PCB

madalinaandronache, 2025-04-09:
Acest issue urmărește problemele legate de PCB și marcaje/documentație PCB, identificate în timpul review-ului:
- [x] Silkscreen
- [x] Tracebility markings not provided
- [x] Via Stitching not applied

Closed 2025-04-10.

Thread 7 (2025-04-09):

Silkscreen

madalinaandronache, 2025-04-09:
Numele componentelor (ex: R1, C3, U5 etc.) nu sunt vizibile pe stratul de silkscreen, ceea ce îngreunează procesul de asamblare, depanare și inspecție vizuală.

Closed 2025-04-10.

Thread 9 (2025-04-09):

Via Stitching not applied

madalinaandronache, 2025-04-09:
Via stitching între planurile de masă lipsește în acest moment, în special în zona modulului ESP32. Acest lucru poate afecta negativ integritatea semnalului, comportamentul EMI și căile de retur pentru masă.

Closed 2025-04-10.

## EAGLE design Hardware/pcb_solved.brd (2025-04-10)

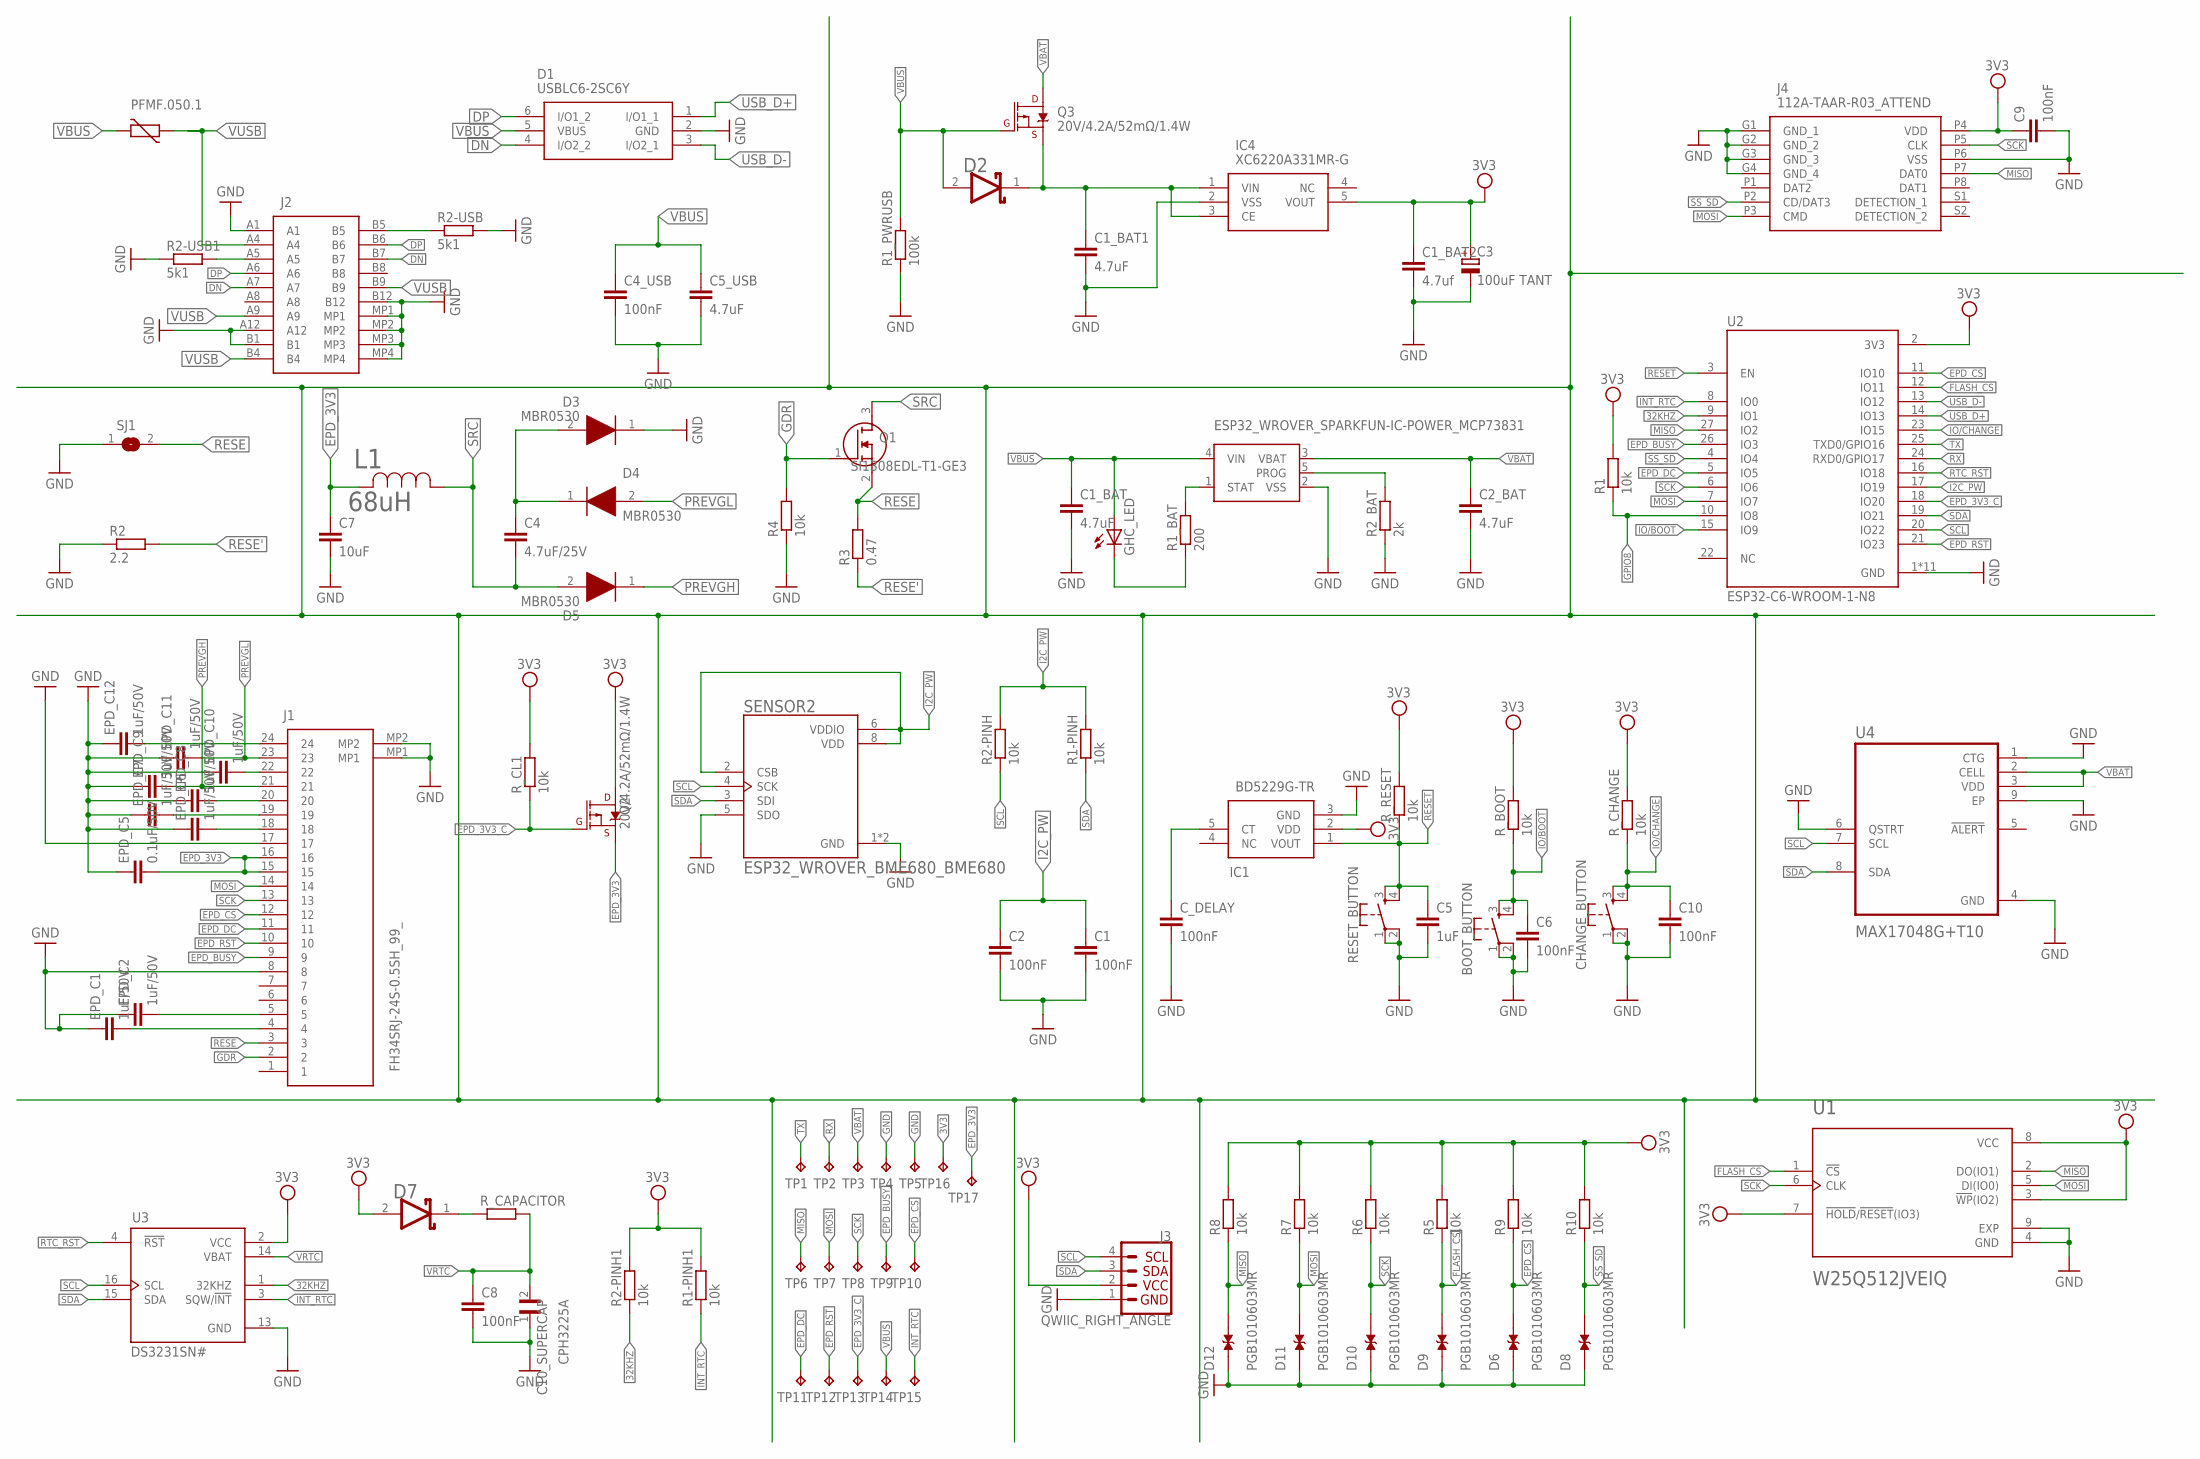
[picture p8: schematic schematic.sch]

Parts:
BOOT_BUTTON: BUTTON_CUSYOMV1; MYBUTTON
C1, C2, C4_USB, C6, C8, C9, C10: 100nF; ESP32_WROVER_EAGLE-LTSPICE_C0402
C1_BAT, C1_BAT1, C2_BAT: 4.7uF; EAGLE-LTSPICE_C0402
C1_BAT2: 4.7uf; EAGLE-LTSPICE_C0402
C3: 100uF TANT; RCL_CT3528
C4: 4.7uF/25V; ESP32_WROVER_EAGLE-LTSPICE_C0402
C5: 1uF; ESP32_WROVER_EAGLE-LTSPICE_C0402
C5_USB: 4.7uF; ESP32_WROVER_EAGLE-LTSPICE_C0402
C7: 10uF; ESP32_WROVER_EAGLE-LTSPICE_C0402
C10_SUPERCAP: CPH3225A; CAPCP3225X100N
CHANGE_BUTTON: BUTTON_CUSYOMV1; MYBUTTON
C_DELAY: 100nF; ESP32_WROVER_EAGLE-LTSPICE_C0402
D1: USBLC6-2SC6Y; SOT95P280X145-6N
D2, D7: ESP32_WROVER_AVX---SD0805S020S1R0_AVX_SD0805S020S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; ESP32_WROVER_AVX---SD0805S020S1R0_AVX_SD0805S020S1R0_0
D3, D4, D5: MBR0530; SOD3716X135N
D6, D8, D9, D10, D11, D12: PGB1010603MR; DIOC1608X36N
EPD_C1, EPD_C2, EPD_C6, EPD_C7, EPD_C8, EPD_C9, EPD_C10, EPD_C11, EPD_C12: 1uF/50V; ESP32_WROVER_EAGLE-LTSPICE_C0402
EPD_C5: 0.1uF/50V; ESP32_WROVER_EAGLE-LTSPICE_C0402
GHC_LED: ADAFRUIT_LEDCHIP-LED0603; ADAFRUIT_CHIP-LED0603
IC1: BD5229G-TR; SOT95P280X125-5N
IC4: XC6220A331MR-G; SOT95P280X120-5N
J1: FH34SRJ-24S-0.5SH_99_; FH34SRJ24S05SH99
J2: SAMACSYS_PARTS_USB4110-GF-A; SAMACSYS_PARTS_USB4110GFA
J3: QWIIC_RIGHT_ANGLE; JST04_1MM_RA
J4: 112A-TAAR-R03_ATTEND; 112ATAARR03ATTEND
L1: 68uH; IND_4828-WE-TPC_WRE
PFMF.050.1: ESP32C6_VARISTORCN1812; ESP32C6_VARISTOR_CT/CN1812
Q1: SI1308EDL-T1-GE3; SOT65P210X110-3N
Q2, Q3: 20V/4.2A/52mΩ/1.4W; ESP32_WROVER_SPARKFUN-DISCRETESEMI_SOT23-3
R1, R1-PINH, R1-PINH1, R2-PINH, R2-PINH1, R4, R5, R6, R7, R8, R9, R10: 10k; ESP32_WROVER_EAGLE-LTSPICE_R0402
R1_BAT: 200; ESP32_WROVER_EAGLE-LTSPICE_R0402
R1_PWRUSB: 100k; ESP32_WROVER_EAGLE-LTSPICE_R0402
R2: 2.2; ESP32_WROVER_EAGLE-LTSPICE_R0402
R2-USB, R2-USB1: 5k1; ESP32_WROVER_EAGLE-LTSPICE_R0402
R2_BAT: 2k; ESP32_WROVER_EAGLE-LTSPICE_R0402
R3: 0.47; ESP32_WROVER_EAGLE-LTSPICE_R0402
RESET_BUTTON: BUTTON_CUSYOMV1; MYBUTTON
R_BOOT: 10k; ESP32_WROVER_EAGLE-LTSPICE_R0402
R_CAPACITOR: ESP32_WROVER_EAGLE-LTSPICE_RR0402; ESP32_WROVER_EAGLE-LTSPICE_R0402
R_CHANGE: 10k; ESP32_WROVER_EAGLE-LTSPICE_R0402
R_CL1: 10k; ESP32_WROVER_EAGLE-LTSPICE_R0402
R_RESET: 10k; ESP32_WROVER_EAGLE-LTSPICE_R0402
SENSOR2: ESP32_WROVER_BME680_BME680; ESP32_WROVER_BME680_PSON80P300X300X100-8N
SJ1: SJ
TP1, TP2, TP3, TP4, TP5, TP6, TP7, TP8, TP9, TP10, TP11, TP12, TP13, TP14, TP15, TP16, TP17: TPTP20R; TP20R
U: ESP32_WROVER_SPARKFUN-IC-POWER_MCP73831; ESP32_WROVER_SPARKFUN-IC-POWER_SOT23-5
U1: W25Q512JVEIQ; SON127P600X800X80-9N
U2: ESP32-C6-WROOM-1-N8; XCVR_ESP32-C6-WROOM-1-N8
U3: DS3231SN#; SOIC127P1032X265-16N
U4: MAX17048G+T10; SON50P200X200X80-9N

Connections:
3V3: C1_BAT2.1, C3.+, C9.1, D7.2 (ANODE), IC1.2 (VDD), IC4.5 (VOUT), J3.2, J4.P4 (VDD), Q2.3 (D), R1.2, R1-PINH1.2, R2-PINH1.2, R5.2, R6.2, R7.2, R8.2, R9.2, R10.2, R_BOOT.2, R_CHANGE.2, R_CL1.2, R_RESET.2, TP16.TP, U1.3 (!WP!(IO2)), U1.7 (!HOLD!/!RESET!(IO3)), U1.8 (VCC), U2.2 (3V3), U3.2 (VCC)
32KHZ: R2-PINH1.1, U2.9 (IO1), U3.1 (32KHZ)
DN: D1.4 (I/O2_2), J2.A7, J2.B7
DP: D1.6 (I/O1_2), J2.A6, J2.B6
EPD_3V3: C7.1, EPD_C5.2, J1.15, J1.16, L1.2, Q2.2 (S), TP17.TP
EPD_3V3_C: Q2.1 (G), R_CL1.1, TP13.TP, U2.18 (IO20)
EPD_BUSY: J1.9, TP9.TP, U2.26 (IO3)
EPD_CS: D6.2, J1.12, R9.1, TP10.TP, U2.11 (IO10)
EPD_DC: J1.11, TP11.TP, U2.5 (IO5)
EPD_RST: J1.10, TP12.TP, U2.21 (IO23)
FLASH_CS: D9.2, R5.1, U1.1 (!CS), U2.12 (IO11)
GDR: J1.2, Q1.1 (G), R4.2
GND: BOOT_BUTTON.1, BOOT_BUTTON.2, C1.2, C1_BAT.2, C1_BAT1.2, C1_BAT2.2, C2.2, C2_BAT.2, C3.-, C4_USB.2, C5.2, C5_USB.2, C6.2, C7.2, C8.2, C9.2, C10.2, C10_SUPERCAP.1, CHANGE_BUTTON.1, CHANGE_BUTTON.2, C_DELAY.2, D1.2 (GND), D3.1 (K), D6.1, D8.1, D9.1, D10.1, D11.1, D12.1, EPD_C1.1, EPD_C2.1, EPD_C5.1, EPD_C6.1, EPD_C7.1, EPD_C8.1, EPD_C9.1, EPD_C10.1, EPD_C11.1, EPD_C12.1, IC1.3 (GND), IC4.2 (VSS), J1.8, J1.17, J1.MP1, J1.MP2, J2.A1, J2.A12, J2.B1, J2.B12, J2.MP1, J2.MP2, J2.MP3, J2.MP4, J3.1, J4.G1 (GND_1), J4.G2 (GND_2), J4.G3 (GND_3), J4.G4 (GND_4), J4.P6 (VSS), R1_PWRUSB.1, R2.1, R2-USB.2, R2-USB1.1, R2_BAT.1, R4.1, RESET_BUTTON.1, RESET_BUTTON.2, SENSOR2.1 (GND), SENSOR2.5 (SDO), SENSOR2.7 (GND), SJ1.1, TP4.TP, TP5.TP, U.2 (VSS), U1.4 (GND), U1.9 (EXP), U2.1 (GND), U2.28 (GND), U2.29_1 (GND), U2.29_2 (GND), U2.29_3 (GND), U2.29_4 (GND), U2.29_5 (GND), U2.29_6 (GND), U2.29_7 (GND), U2.29_8 (GND), U2.29_9 (GND), U3.13 (GND), U4.1 (CTG), U4.4 (GND), U4.6 (QSTRT), U4.9 (EP)
GPIO8: R1.1, U2.10 (IO8)
I2C_PW: C1.1, C2.1, R1-PINH.2, R2-PINH.2, SENSOR2.2 (CSB), SENSOR2.6 (VDDIO), SENSOR2.8 (VDD), U2.17 (IO19)
INT_RTC: R1-PINH1.1, TP15.TP, U2.8 (IO0), U3.3 (SQW/!INT)
IO/BOOT: BOOT_BUTTON.3, BOOT_BUTTON.4, C6.1, R_BOOT.1, U2.15 (IO9)
IO/CHANGE: C10.1, CHANGE_BUTTON.3, CHANGE_BUTTON.4, R_CHANGE.1, U2.23 (IO15)
MISO: D12.2, J4.P7 (DAT0), R8.1, TP6.TP, U1.2 (DO(IO1)), U2.27 (IO2)
MOSI: D11.2, J1.14, J4.P3 (CMD), R7.1, TP7.TP, U1.5 (DI(IO0)), U2.7 (IO7)
unnamed: J2.A5, R2-USB1.2
unnamed: J2.B5, R2-USB.1
unnamed: C4.1, D3.2 (A), D4.1 (K)
unnamed: EPD_C2.2, J1.5
unnamed: EPD_C1.2, J1.4
unnamed: EPD_C6.2, J1.18
unnamed: EPD_C8.2, J1.20
unnamed: EPD_C7.2, J1.19
unnamed: EPD_C12.2, J1.24
unnamed: EPD_C10.2, J1.22
unnamed: D7.1 (CATHODE), R_CAPACITOR.1
unnamed: C1_BAT1.1, D2.1 (CATHODE), IC4.1 (VIN), IC4.3 (CE), Q3.2 (S)
unnamed: R1_BAT.2, U.1 (STAT)
unnamed: GHC_LED.C, R1_BAT.1
unnamed: C_DELAY.1, IC1.5 (CT)
unnamed: R2_BAT.2, U.5 (PROG)
PREVGH: D5.1 (K), EPD_C9.2, J1.21
PREVGL: D4.2 (A), EPD_C11.2, J1.23
RESE: J1.3, Q1.2 (S), R3.2, SJ1.2
RESE': R2.2, R3.1
RESET: C5.1, IC1.1 (VOUT), RESET_BUTTON.3, RESET_BUTTON.4, R_RESET.1, U2.3 (EN)
RTC_RST: U2.16 (IO18), U3.4 (!RST)
RX: TP2.TP, U2.24 (RXD0/GPIO17)
SCK: D10.2, J1.13, J4.P5 (CLK), R6.1, TP8.TP, U1.6 (CLK), U2.6 (IO6)
SCL: J3.4, R2-PINH.1, SENSOR2.4 (SCK), U2.20 (IO22), U3.16 (SCL), U4.7 (SCL)
SDA: J3.3, R1-PINH.1, SENSOR2.3 (SDI), U2.19 (IO21), U3.15 (SDA), U4.8 (SDA)
SRC: C4.2, D5.2 (A), L1.1, Q1.3 (D)
SS_SD: D8.2, J4.P2 (CD/DAT3), R10.1, U2.4 (IO4)
TX: TP1.TP, U2.25 (TXD0/GPIO16)
USB_D+: D1.1 (I/O1_1), U2.14 (IO13)
USB_D-: D1.3 (I/O2_1), U2.13 (IO12)
VBAT: C2_BAT.1, Q3.3 (D), TP3.TP, U.3 (VBAT), U4.2 (CELL), U4.3 (VDD)
VBUS: C1_BAT.1, C4_USB.1, C5_USB.1, D1.5 (VBUS), D2.2 (ANODE), GHC_LED.A, PFMF.050.1.2, Q3.1 (G), R1_PWRUSB.2, TP14.TP, U.4 (VIN)
VRTC: C8.1, C10_SUPERCAP.2, R_CAPACITOR.2, U3.14 (VBAT)
VUSB: J2.A4, J2.A9, J2.B4, J2.B9, PFMF.050.1.1

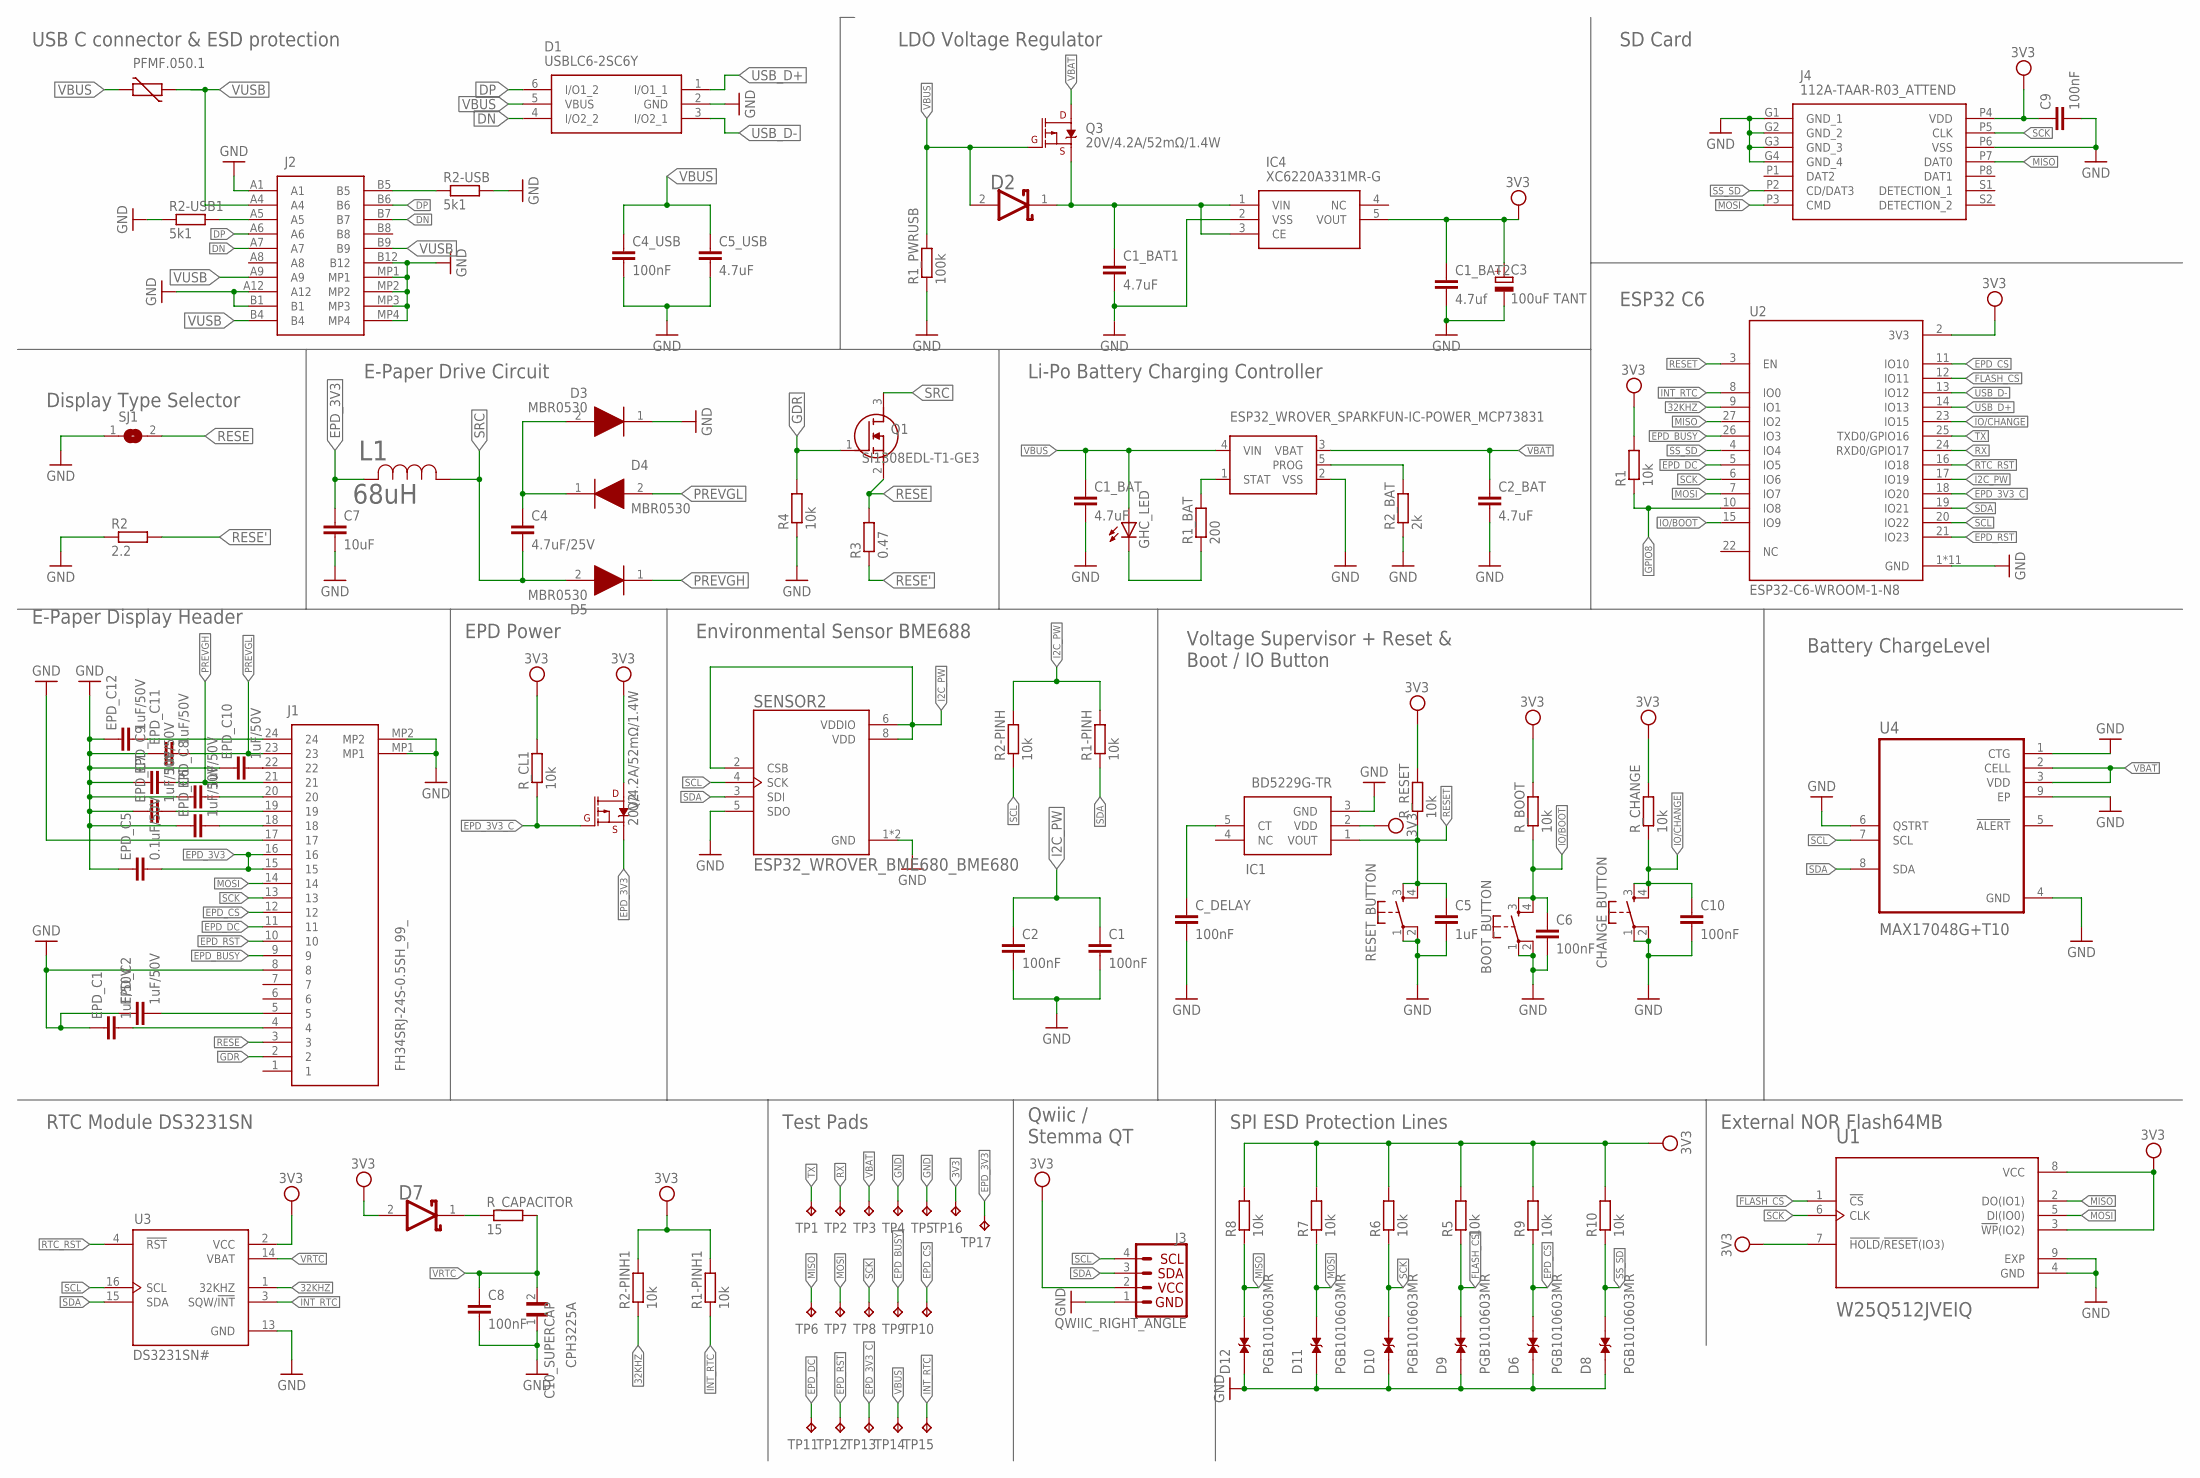
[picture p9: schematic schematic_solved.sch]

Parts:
BOOT_BUTTON: BUTTON_CUSYOMV1; MYBUTTON
C1, C2, C4_USB, C6, C8, C9, C10: 100nF; ESP32_WROVER_EAGLE-LTSPICE_C0402
C1_BAT, C1_BAT1, C2_BAT: 4.7uF; EAGLE-LTSPICE_C0402
C1_BAT2: 4.7uf; EAGLE-LTSPICE_C0402
C3: 100uF TANT; RCL_CT3528
C4: 4.7uF/25V; ESP32_WROVER_EAGLE-LTSPICE_C0402
C5: 1uF; ESP32_WROVER_EAGLE-LTSPICE_C0402
C5_USB: 4.7uF; ESP32_WROVER_EAGLE-LTSPICE_C0402
C7: 10uF; ESP32_WROVER_EAGLE-LTSPICE_C0402
C10_SUPERCAP: CPH3225A; CAPCP3225X100N
CHANGE_BUTTON: BUTTON_CUSYOMV1; MYBUTTON
C_DELAY: 100nF; ESP32_WROVER_EAGLE-LTSPICE_C0402
D1: USBLC6-2SC6Y; SOT95P280X145-6N
D2, D7: ESP32_WROVER_AVX---SD0805S020S1R0_AVX_SD0805S020S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; ESP32_WROVER_AVX---SD0805S020S1R0_AVX_SD0805S020S1R0_0
D3, D4, D5: MBR0530; SOD3716X135N
D6, D8, D9, D10, D11, D12: PGB1010603MR; DIOC1608X36N
EPD_C1, EPD_C2, EPD_C6, EPD_C7, EPD_C8, EPD_C9, EPD_C10, EPD_C11, EPD_C12: 1uF/50V; ESP32_WROVER_EAGLE-LTSPICE_C0402
EPD_C5: 0.1uF/50V; ESP32_WROVER_EAGLE-LTSPICE_C0402
GHC_LED: ADAFRUIT_LEDCHIP-LED0603; ADAFRUIT_CHIP-LED0603
IC1: BD5229G-TR; SOT95P280X125-5N
IC4: XC6220A331MR-G; SOT95P280X120-5N
J1: FH34SRJ-24S-0.5SH_99_; FH34SRJ24S05SH99
J2: SAMACSYS_PARTS_USB4110-GF-A; SAMACSYS_PARTS_USB4110GFA
J3: QWIIC_RIGHT_ANGLE; JST04_1MM_RA
J4: 112A-TAAR-R03_ATTEND; 112ATAARR03ATTEND
L1: 68uH; IND_4828-WE-TPC_WRE
PFMF.050.1: ESP32C6_VARISTORCN1812; ESP32C6_VARISTOR_CT/CN1812
Q1: SI1308EDL-T1-GE3; SOT65P210X110-3N
Q2, Q3: 20V/4.2A/52mΩ/1.4W; ESP32_WROVER_SPARKFUN-DISCRETESEMI_SOT23-3
R1, R1-PINH, R1-PINH1, R2-PINH, R2-PINH1, R4, R5, R6, R7, R8, R9, R10: 10k; ESP32_WROVER_EAGLE-LTSPICE_R0402
R1_BAT: 200; ESP32_WROVER_EAGLE-LTSPICE_R0402
R1_PWRUSB: 100k; ESP32_WROVER_EAGLE-LTSPICE_R0402
R2: 2.2; ESP32_WROVER_EAGLE-LTSPICE_R0402
R2-USB, R2-USB1: 5k1; ESP32_WROVER_EAGLE-LTSPICE_R0402
R2_BAT: 2k; ESP32_WROVER_EAGLE-LTSPICE_R0402
R3: 0.47; ESP32_WROVER_EAGLE-LTSPICE_R0402
RESET_BUTTON: BUTTON_CUSYOMV1; MYBUTTON
R_BOOT: 10k; ESP32_WROVER_EAGLE-LTSPICE_R0402
R_CAPACITOR: 15; ESP32_WROVER_EAGLE-LTSPICE_R0402
R_CHANGE: 10k; ESP32_WROVER_EAGLE-LTSPICE_R0402
R_CL1: 10k; ESP32_WROVER_EAGLE-LTSPICE_R0402
R_RESET: 10k; ESP32_WROVER_EAGLE-LTSPICE_R0402
SENSOR2: ESP32_WROVER_BME680_BME680; ESP32_WROVER_BME680_PSON80P300X300X100-8N
SJ1: SJ
TP1, TP2, TP3, TP4, TP5, TP6, TP7, TP8, TP9, TP10, TP11, TP12, TP13, TP14, TP15, TP16, TP17: TPTP20R; TP20R
U: ESP32_WROVER_SPARKFUN-IC-POWER_MCP73831; ESP32_WROVER_SPARKFUN-IC-POWER_SOT23-5
U1: W25Q512JVEIQ; SON127P600X800X80-9N
U2: ESP32-C6-WROOM-1-N8; XCVR_ESP32-C6-WROOM-1-N8
U3: DS3231SN#; SOIC127P1032X265-16N
U4: MAX17048G+T10; SON50P200X200X80-9N

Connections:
3V3: C1_BAT2.1, C3.+, C9.1, D7.2 (ANODE), IC1.2 (VDD), IC4.5 (VOUT), J3.2, J4.P4 (VDD), Q2.3 (D), R1.2, R1-PINH1.2, R2-PINH1.2, R5.2, R6.2, R7.2, R8.2, R9.2, R10.2, R_BOOT.2, R_CHANGE.2, R_CL1.2, R_RESET.2, TP16.TP, U1.3 (!WP!(IO2)), U1.7 (!HOLD!/!RESET!(IO3)), U1.8 (VCC), U2.2 (3V3), U3.2 (VCC)
32KHZ: R2-PINH1.1, U2.9 (IO1), U3.1 (32KHZ)
DN: D1.4 (I/O2_2), J2.A7, J2.B7
DP: D1.6 (I/O1_2), J2.A6, J2.B6
EPD_3V3: C7.1, EPD_C5.2, J1.15, J1.16, L1.2, Q2.2 (S), TP17.TP
EPD_3V3_C: Q2.1 (G), R_CL1.1, TP13.TP, U2.18 (IO20)
EPD_BUSY: J1.9, TP9.TP, U2.26 (IO3)
EPD_CS: D6.2, J1.12, R9.1, TP10.TP, U2.11 (IO10)
EPD_DC: J1.11, TP11.TP, U2.5 (IO5)
EPD_RST: J1.10, TP12.TP, U2.21 (IO23)
FLASH_CS: D9.2, R5.1, U1.1 (!CS), U2.12 (IO11)
GDR: J1.2, Q1.1 (G), R4.2
GND: BOOT_BUTTON.1, BOOT_BUTTON.2, C1.2, C1_BAT.2, C1_BAT1.2, C1_BAT2.2, C2.2, C2_BAT.2, C3.-, C4_USB.2, C5.2, C5_USB.2, C6.2, C7.2, C8.2, C9.2, C10.2, C10_SUPERCAP.1, CHANGE_BUTTON.1, CHANGE_BUTTON.2, C_DELAY.2, D1.2 (GND), D3.1 (K), D6.1, D8.1, D9.1, D10.1, D11.1, D12.1, EPD_C1.1, EPD_C2.1, EPD_C5.1, EPD_C6.1, EPD_C7.1, EPD_C8.1, EPD_C9.1, EPD_C10.1, EPD_C11.1, EPD_C12.1, IC1.3 (GND), IC4.2 (VSS), J1.8, J1.17, J1.MP1, J1.MP2, J2.A1, J2.A12, J2.B1, J2.B12, J2.MP1, J2.MP2, J2.MP3, J2.MP4, J3.1, J4.G1 (GND_1), J4.G2 (GND_2), J4.G3 (GND_3), J4.G4 (GND_4), J4.P6 (VSS), R1_PWRUSB.1, R2.1, R2-USB.2, R2-USB1.1, R2_BAT.1, R4.1, RESET_BUTTON.1, RESET_BUTTON.2, SENSOR2.1 (GND), SENSOR2.5 (SDO), SENSOR2.7 (GND), SJ1.1, TP4.TP, TP5.TP, U.2 (VSS), U1.4 (GND), U1.9 (EXP), U2.1 (GND), U2.28 (GND), U2.29_1 (GND), U2.29_2 (GND), U2.29_3 (GND), U2.29_4 (GND), U2.29_5 (GND), U2.29_6 (GND), U2.29_7 (GND), U2.29_8 (GND), U2.29_9 (GND), U3.13 (GND), U4.1 (CTG), U4.4 (GND), U4.6 (QSTRT), U4.9 (EP)
GPIO8: R1.1, U2.10 (IO8)
I2C_PW: C1.1, C2.1, R1-PINH.2, R2-PINH.2, SENSOR2.2 (CSB), SENSOR2.6 (VDDIO), SENSOR2.8 (VDD), U2.17 (IO19)
INT_RTC: R1-PINH1.1, TP15.TP, U2.8 (IO0), U3.3 (SQW/!INT)
IO/BOOT: BOOT_BUTTON.3, BOOT_BUTTON.4, C6.1, R_BOOT.1, U2.15 (IO9)
IO/CHANGE: C10.1, CHANGE_BUTTON.3, CHANGE_BUTTON.4, R_CHANGE.1, U2.23 (IO15)
MISO: D12.2, J4.P7 (DAT0), R8.1, TP6.TP, U1.2 (DO(IO1)), U2.27 (IO2)
MOSI: D11.2, J1.14, J4.P3 (CMD), R7.1, TP7.TP, U1.5 (DI(IO0)), U2.7 (IO7)
unnamed: J2.A5, R2-USB1.2
unnamed: J2.B5, R2-USB.1
unnamed: C4.1, D3.2 (A), D4.1 (K)
unnamed: EPD_C2.2, J1.5
unnamed: EPD_C1.2, J1.4
unnamed: EPD_C6.2, J1.18
unnamed: EPD_C8.2, J1.20
unnamed: EPD_C7.2, J1.19
unnamed: EPD_C12.2, J1.24
unnamed: EPD_C10.2, J1.22
unnamed: D7.1 (CATHODE), R_CAPACITOR.1
unnamed: C1_BAT1.1, D2.1 (CATHODE), IC4.1 (VIN), IC4.3 (CE), Q3.2 (S)
unnamed: R1_BAT.2, U.1 (STAT)
unnamed: GHC_LED.C, R1_BAT.1
unnamed: C_DELAY.1, IC1.5 (CT)
unnamed: R2_BAT.2, U.5 (PROG)
PREVGH: D5.1 (K), EPD_C9.2, J1.21
PREVGL: D4.2 (A), EPD_C11.2, J1.23
RESE: J1.3, Q1.2 (S), R3.2, SJ1.2
RESE': R2.2, R3.1
RESET: C5.1, IC1.1 (VOUT), RESET_BUTTON.3, RESET_BUTTON.4, R_RESET.1, U2.3 (EN)
RTC_RST: U2.16 (IO18), U3.4 (!RST)
RX: TP2.TP, U2.24 (RXD0/GPIO17)
SCK: D10.2, J1.13, J4.P5 (CLK), R6.1, TP8.TP, U1.6 (CLK), U2.6 (IO6)
SCL: J3.4, R2-PINH.1, SENSOR2.4 (SCK), U2.20 (IO22), U3.16 (SCL), U4.7 (SCL)
SDA: J3.3, R1-PINH.1, SENSOR2.3 (SDI), U2.19 (IO21), U3.15 (SDA), U4.8 (SDA)
SRC: C4.2, D5.2 (A), L1.1, Q1.3 (D)
SS_SD: D8.2, J4.P2 (CD/DAT3), R10.1, U2.4 (IO4)
TX: TP1.TP, U2.25 (TXD0/GPIO16)
USB_D+: D1.1 (I/O1_1), U2.14 (IO13)
USB_D-: D1.3 (I/O2_1), U2.13 (IO12)
VBAT: C2_BAT.1, Q3.3 (D), TP3.TP, U.3 (VBAT), U4.2 (CELL), U4.3 (VDD)
VBUS: C1_BAT.1, C4_USB.1, C5_USB.1, D1.5 (VBUS), D2.2 (ANODE), GHC_LED.A, PFMF.050.1.2, Q3.1 (G), R1_PWRUSB.2, TP14.TP, U.4 (VIN)
VRTC: C8.1, C10_SUPERCAP.2, R_CAPACITOR.2, U3.14 (VBAT)
VUSB: J2.A4, J2.A9, J2.B4, J2.B9, PFMF.050.1.1

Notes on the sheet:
USB C connector & ESD protection
LDO Voltage Regulator
SD Card
ESP32 C6
Display Type Selector
E-Paper Drive Circuit
Li-Po Battery Charging Controller
Battery ChargeLevel
Voltage Supervisor + Reset & Boot / IO Button
Environmental Sensor BME688
EPD Power
E-Paper Display Header
RTC Module DS3231SN
Test Pads
Qwiic / Stemma QT
SPI ESD Protection Lines
External NOR Flash64MB

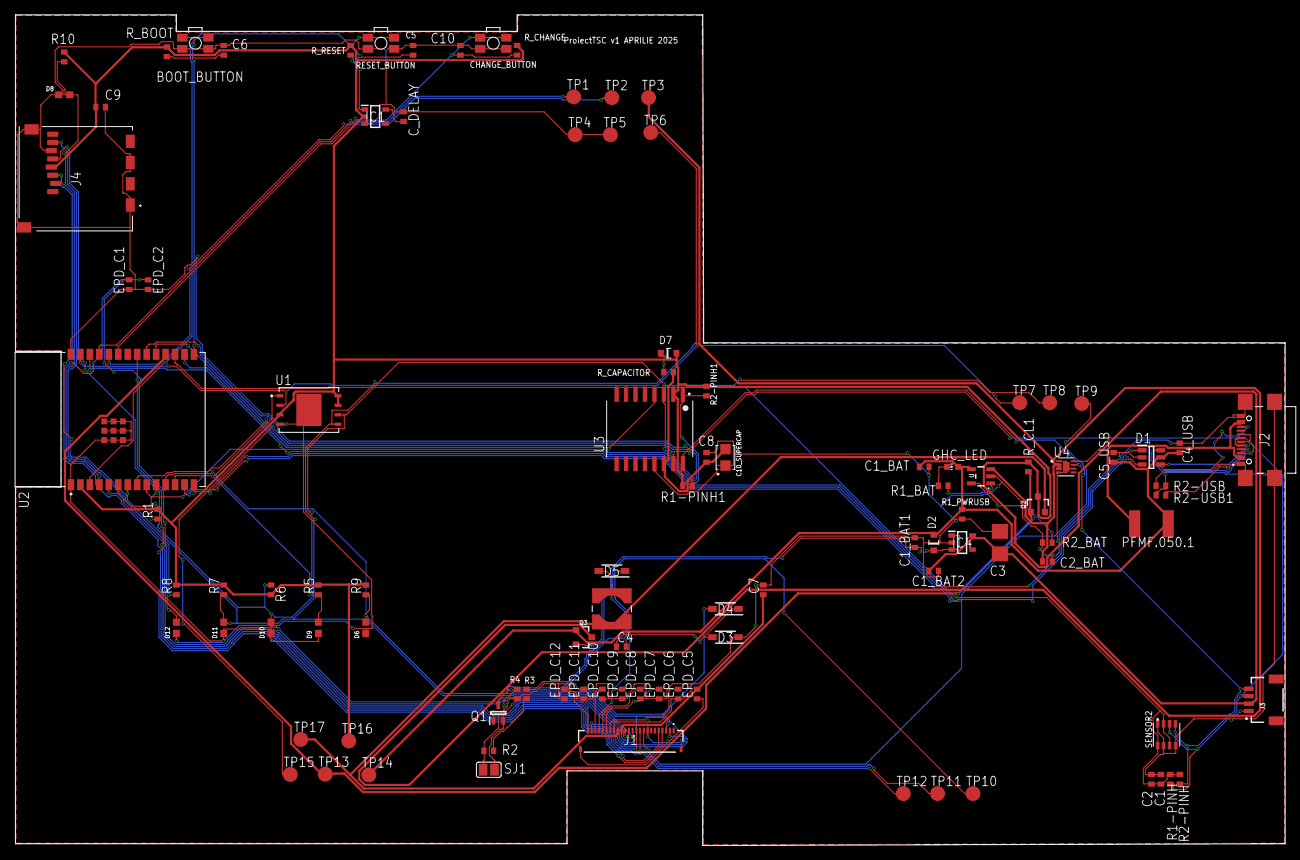
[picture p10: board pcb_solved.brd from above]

Board: 2 copper layers, 170.3 x 111.4 mm, 103 parts (0 on the bottom side), 55 nets.

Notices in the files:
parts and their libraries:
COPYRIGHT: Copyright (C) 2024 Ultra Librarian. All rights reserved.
